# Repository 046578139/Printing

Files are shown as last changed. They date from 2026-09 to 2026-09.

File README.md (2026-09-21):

# NVG objective cap set

A four-piece 3D-printed objective cap system for NOCTIS mil-spec glass in
Nocturn Industries Raptor housings (AN/PVS-14-pattern objective interface),
retained with 1/8 in shock cord.

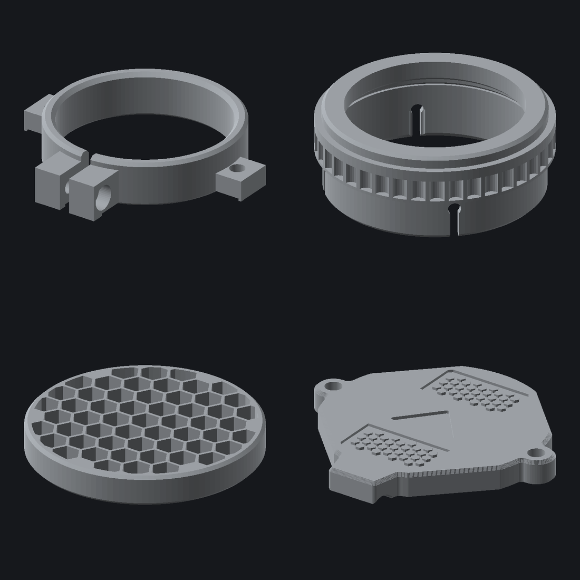
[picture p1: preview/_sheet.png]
parts


> ## Read this first
>
> **Front bezel: confirmed at 36.75 in PLA.** The fine ladder picked
> modelled bore 36.90, mid-ladder. That is 1.3 mm under the AN/PVS-14
> nominal this project started from — the nominal was wrong, which is
> exactly why the gauge exists. Valid in PLA only; re-gauge in the
> production filament.
>
> **Collar barrel: still unverified**, and suspect for the same reason.
> Do not print a collar until that number is read off a gauge.
>
> → **[docs/CALIBRATION.md](docs/CALIBRATION.md)** ·
> **[docs/MEASUREMENTS.md](docs/MEASUREMENTS.md)**

## The parts

| File | Part | What it does |
|---|---|---|
| `stl/sweep/cinchS_*.stl` | **Collar, cinch — print these** | Held by a **zip tie**, not by the plastic. 40 N of band tension against the 6 N a PLA spring ring manages, and it does not relax. Three bores covering 35.29–41.20 so the ungauged seat stops mattering; print all three, fit the one that lands. 9.00 mm tall so it clears a narrow locking collar. **Goes on BEFORE the housing.** |
| `stl/01g_collar_cinch.stl` | Collar, cinch (11 mm) | Same part, full height. Wider tie channel and thicker ears — use it only once you know the locking collar band is at least 11 mm wide. |
| `stl/01f_collar_lap.stl` | Collar, lapped | On ice, and worth revisiting in PAHT-CF. The recorder mount's actual mechanism: the band wraps 414° so its two ends lap past each other, each carrying a finger tab. **Squeeze** the tabs together and the lap shortens, which makes the circle bigger. 2.6 N — the lightest squeeze of any collar here. No hardware, no tools — [how it works](docs/ASSEMBLY.md#01f-is-the-one-to-print). **Goes on BEFORE the housing.** |
| `stl/01e_collar_pinch.stl` | Collar, pinch | Reads closed at 340°, tabs flanking a gap — you **spread** these, not squeeze them. Lowest install strain in the set and no sliding clearance for a slicer to get wrong, so it is the fallback if `01f`'s lap fuses. **Goes on BEFORE the housing.** |
| `stl/01_collar.stl` | Collar, screw clamp | Split band clamp, M3 pinch screw. The only one that can be fitted *after* the housing, and the only one with a preload you can re-tighten. |
| `stl/01b_collar_proto.stl` | Collar, wide gap | Prototype only. Opens far enough to clamp anywhere across the plausible range, for use before the collar seat has been gauged. Needs an M3 × 30 screw. |
| `stl/01c_collar_snap.stl` | Collar, push-on | Split C-ring, 230° wrap. Pushed straight on; the barrel cams it open. Superseded by `01e` — kept because it is the only spring ring that does not need an axial approach. |
| `stl/01d_collar_lever.stl` | Collar, lever | Circlip-style, 290° wrap with finger paddles. Superseded by `01e`, which does the same job at 340° for less strain and less force. |
| `stl/02b_killflash_housing_solid.stl` | Housing, no collet | Same housing with the collet slots deleted. Cleaner and stiffer, but a press roughly **1.7× tighter** — to fit *and* to remove. |
| `stl/02_killflash_housing.stl` | Kill flash housing | Presses onto the objective bezel, carries the kill flash, gives the cap a register to close on. |
| `stl/03_killflash_insert.stl` | Kill flash | Printed honeycomb. 71 % open area, 39° off-axis cutoff. |
| `stl/04_flip_cap.stl` | Flip cap | Bungee-retained cover. Cord bosses at 3 and 9, thumb tab at 6, hex grip, centre mark. |
| `stl/05_gauge_shroud.stl` | Fit gauge | Ring ladder for the housing bore. **Print this first.** |
| `stl/06_gauge_collar.stl` | Fit gauge | Ring ladder for the collar bore. **Print this first.** |
| `stl/sweep/lap_*.stl` | Fit sweep | Five `01f` collars stepping 0.30 mm, bore size moulded into each ear. Settles the collar seat *and* the grip on one plate — the last unverified dimension in the set. |

Every part is symmetric about the vertical plane — there is no left and
right. Print two of each for a binocular.

### Prototyping in PLA

Everything is calibrated for PLA right now (`CAL_MATERIAL == PRINT_MATERIAL`,
so the bore bias is exactly zero — the measured case). Print the whole set
in PLA, use `01b_collar_proto` in place of the collar, and you can shake
down cord routing, flip clearance, IPD spacing and glove ergonomics before
the collar barrel has been gauged and before committing any engineering
filament.

**Do not field a PLA set.** It creeps under the collet's sustained hoop load
and softens around 55–60 °C; an afternoon on a dashboard will destroy it.

## Quick start

```bash
python3 build.py        # writes one STL per part into stl/
python3 tests.py        # 332 geometry and interface checks
python3 render.py       # PNG previews into preview/
```

Fine-tune a fit without touching anything else:

```bash
python3 build.py gauge --nominal 38.4 --step 0.1 --count 7
```

Requires `manifold3d`, `trimesh`, `numpy`.

## How it goes together

```
   objective bezel │ kill flash │ housing flange │ register │ cap
   ────────────────┼────────────┼────────────────┼──────────┼──────
       8.0 mm      │   5.0 mm   │     1.6 mm     │  2.2 mm  │ 5.6 mm
                                                                     → +Z
   collar clamps the barrel behind all of this, cord runs forward at r=26
```

The kill flash loads from the **rear** of the housing and seats against an
integral flange, then the objective traps it. No snap ring, no glue, and it
still comes apart for cleaning. → **[docs/ASSEMBLY.md](docs/ASSEMBLY.md)**

## Design notes

**Both cord holes sit on one radius (26.00 mm).** That makes the line
between the two cap bosses the hinge axis, with both holes lying *on* it —
so flipping the cap does not change the cord length. The bungee only
stretches the 2.2 mm needed to clear the register, about 11 % strain.

**Nothing needs an anti-rotation key.** The cap's orientation comes from the
two cords, not from the register, so the housing is free to sit at any
rotation. The collar is screw-clamped because it *is* the rotational datum.

**Every part prints without support.** The housing goes front-face-down so
the kill flash seat becomes an upward-opening pocket; the cap goes
front-face-down so the decorated face gets the plate finish and the grip
texture is debossed rather than raised; the collar's nut trap is rotated
point-up so it bridges itself.

**The housing grip is a four-finger collet, and the fingers are thinner
than the wall.** A solid ring pressed onto an objective barrel has a narrow
acceptance window and puts real hoop stress into an expensive optic. But
slots alone are not enough — radial compliance scales as `t³/L³`, and at the
full 3.4 mm wall the fingers were a stubby plate (L/t = 1.88), not a spring.
There is not enough bezel to lengthen the slots, so the OD is relieved over
the collet instead: 1.90 mm fingers at L/t = 3.16 are **4.7× more
compliant**, at no cost in axial length. Each slot ends in a round keyhole
rather than a flat face, because the root is where it would crack.

**The slots' bore edges are broken.** Four slots leave eight sharp axial
edges in the bore that would otherwise scrape the full grip length of the
bezel on every install. On a coated optic that is the one piece of real
damage this design could do.

**The cap seats on the housing shoulder, not the register.** The pocket is
0.4 mm deeper than the register is tall, so the register locates and the
shoulder takes the load. A cap that lands on the register rocks.

## Layout

```
params.py           every dimension, single source of truth
build.py            emits one STL per part, validates before writing
tests.py            geometry probes + cross-part interface assertions
render.py           headless preview renderer (no GL)
lib/                solids, patterns, seven-segment text
parts/              one module per part
docs/               CALIBRATION, MEASUREMENTS, ASSEMBLY, PRINTING
stl/                output
```

`params.py` is the only file you should need to edit. Two hardware
diameters, plus `CAL_MATERIAL` / `PRINT_MATERIAL` — the bore bias is derived
from those, so changing filament is one line and cannot be got wrong by
forgetting. `BORE_TRIM` is there for a uniform fit correction on top.

## Material

| Part | Material |
|---|---|
| Collar, kill flash housing | **PAHT-CF** — expansion matched to the aluminium bezel, ductile across layers at the collet roots, immune to DEET and CLP |
| Kill flash, flip cap | **ASA Basic** — the 0.45 mm honeycomb wall needs a 0.4 mm nozzle, and CF grades need 0.6 mm hardened; the cap is the only impact-loaded part |
| Prototypes and coarse gauges | **PLA Basic** — not PETG, which is half the stiffness and yields where the production part cracks |
| Fine gauge | **the production filament itself** |

No single material wins all four parts. The reasoning, the tradeoffs being
accepted, and full slicer settings are in
**[docs/PRINTING.md](docs/PRINTING.md)**.

Carbon fibre against a coated objective barrel was **not** cleared — line
the collar bore with 0.13 mm PTFE tape and set `LINER_T = 0.13`.

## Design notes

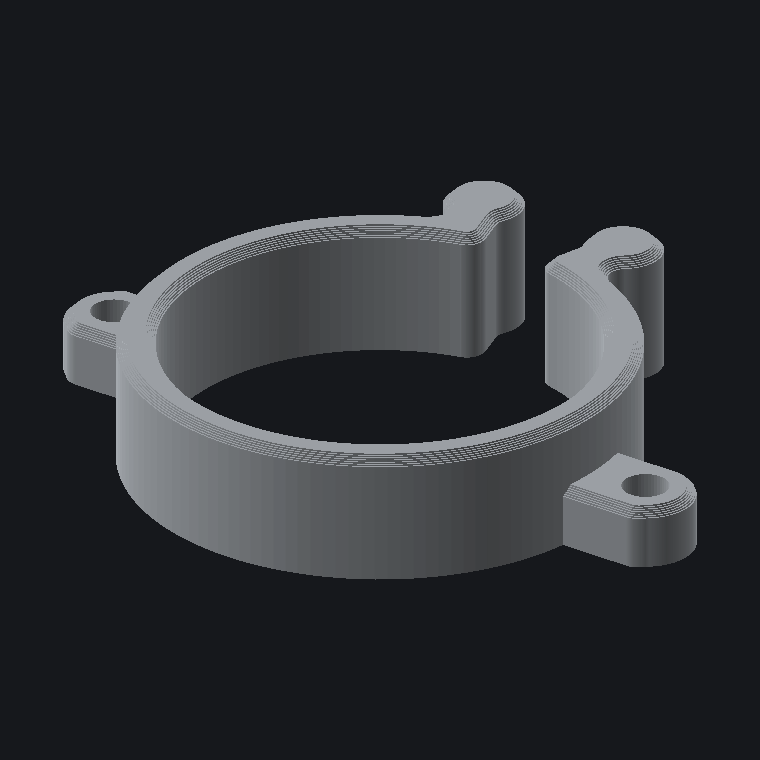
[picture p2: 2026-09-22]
preview/01e_collar_pinch.png

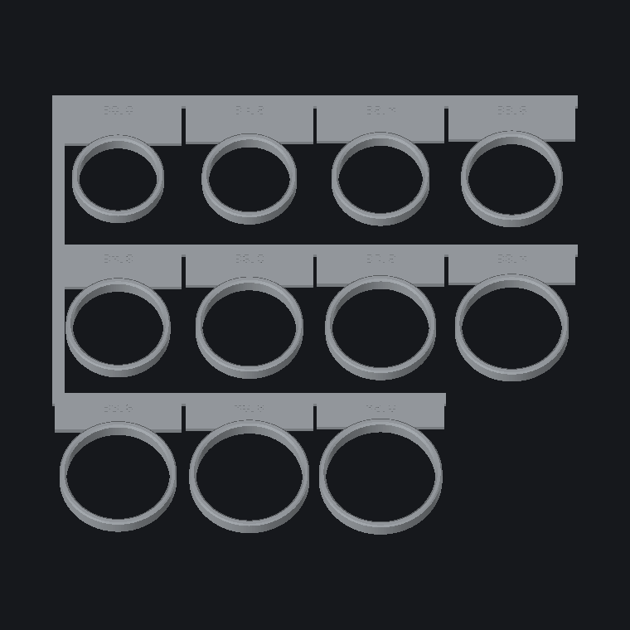
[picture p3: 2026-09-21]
preview/06_gauge_collar_wide.png

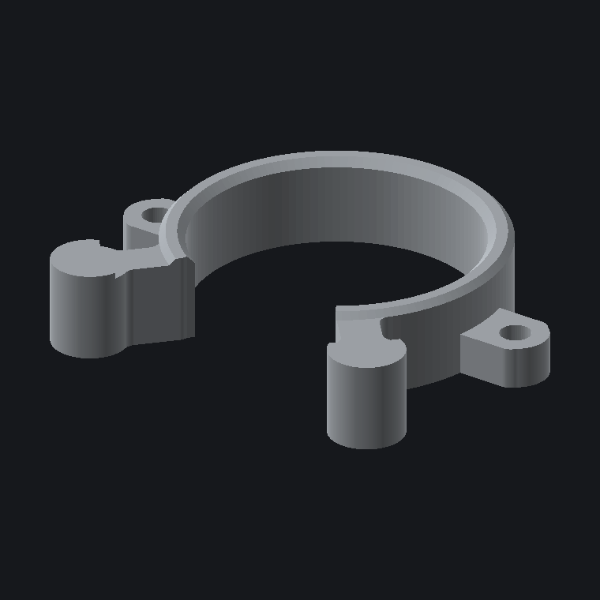
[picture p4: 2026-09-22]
preview/01d_collar_lever.png

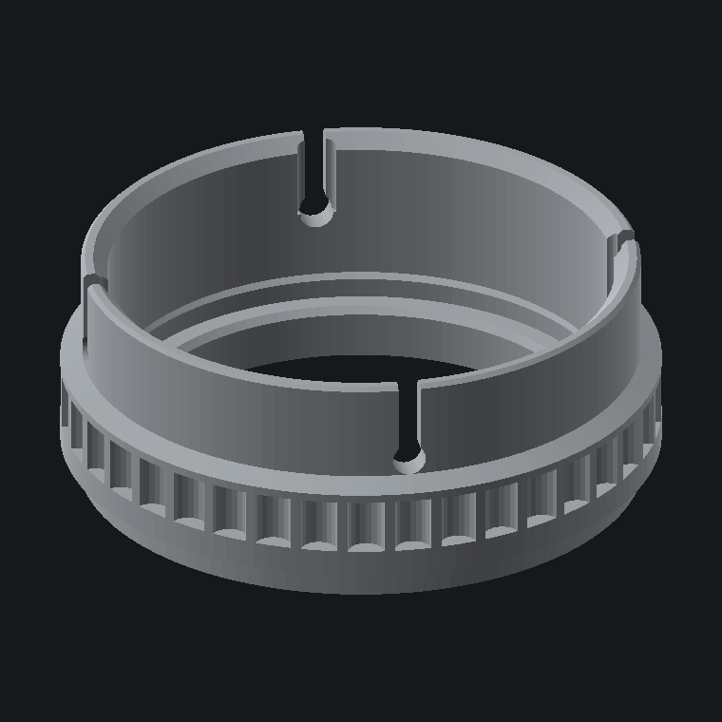
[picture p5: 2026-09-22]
preview/02_killflash_housing.png

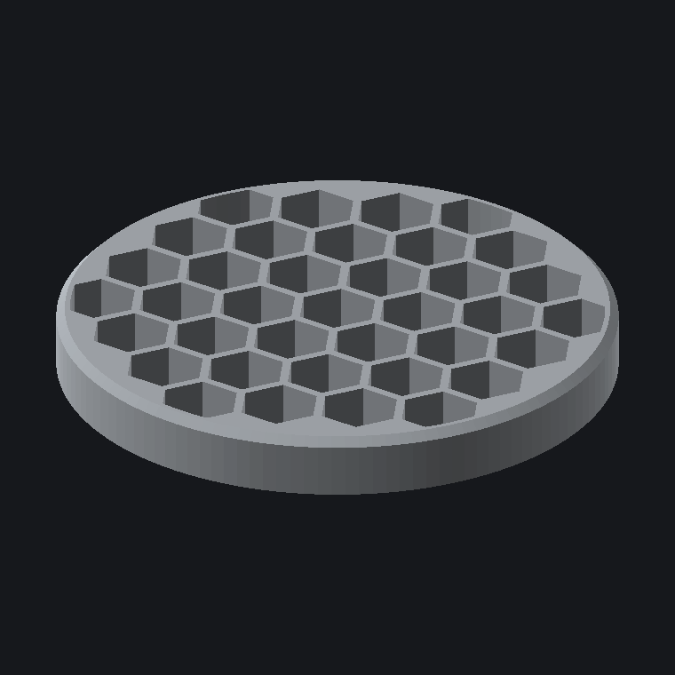
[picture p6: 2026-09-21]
preview/03_killflash_insert.png

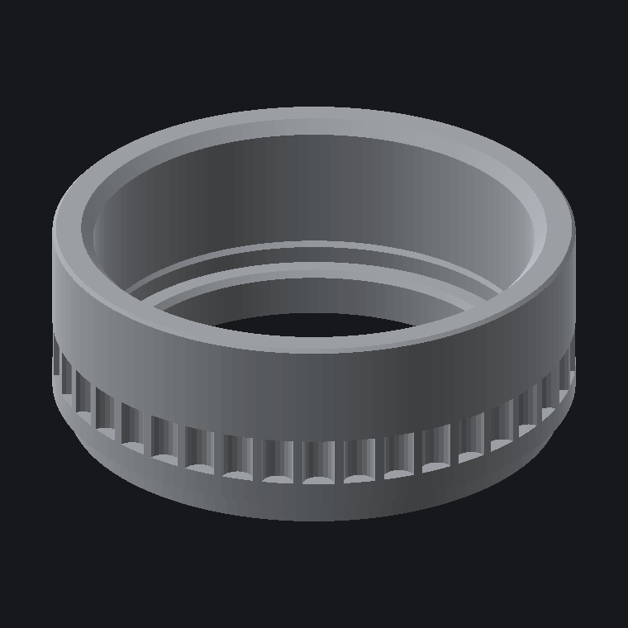
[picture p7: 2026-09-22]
preview/02b_killflash_housing_solid.png

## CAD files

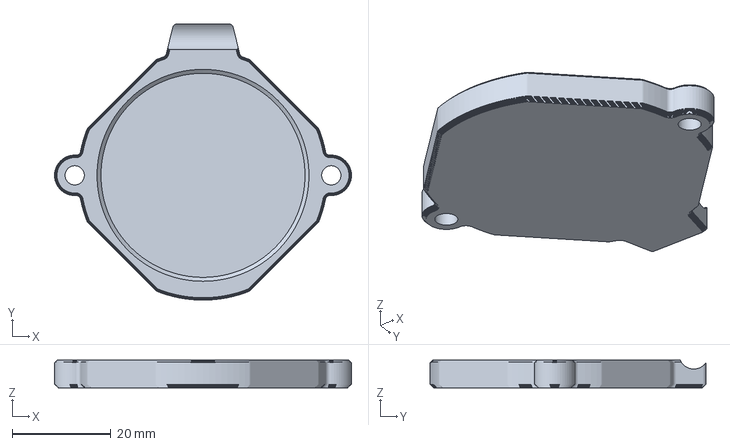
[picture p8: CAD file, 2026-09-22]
stl/20_cap_FUCK_2color.3mf
60.2 x 56.0 x 5.60 mm

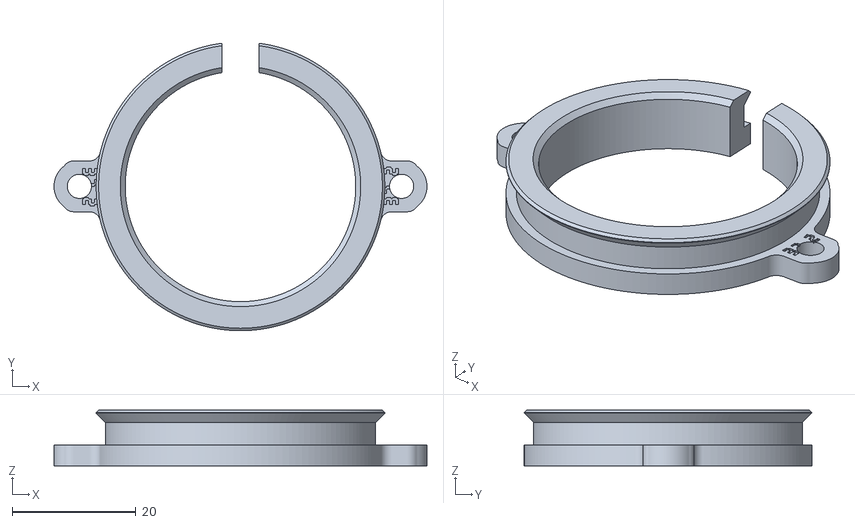
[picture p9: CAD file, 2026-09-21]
stl/sweep/cinchS_37.20.stl
60.2 x 46.4 x 9.00

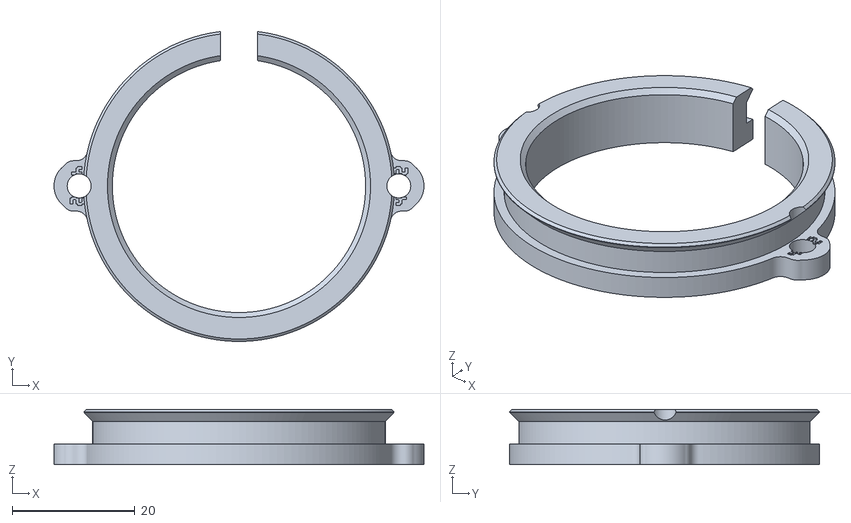
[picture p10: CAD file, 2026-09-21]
stl/sweep/cinchS_41.20.stl
60.2 x 50.4 x 9.00

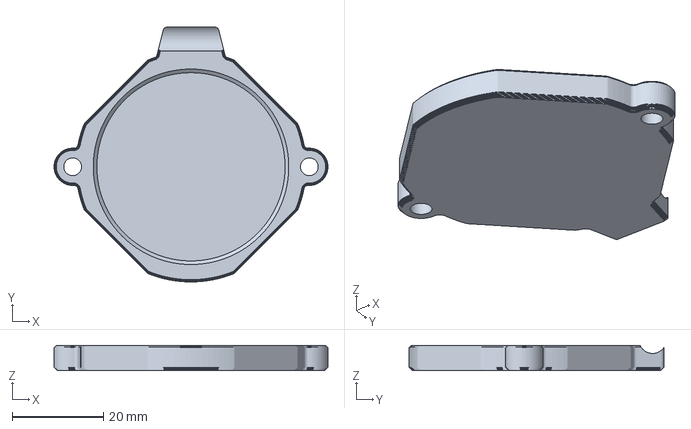
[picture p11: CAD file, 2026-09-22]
stl/23_cap_2color.3mf
60.2 x 56.0 x 5.60 mm

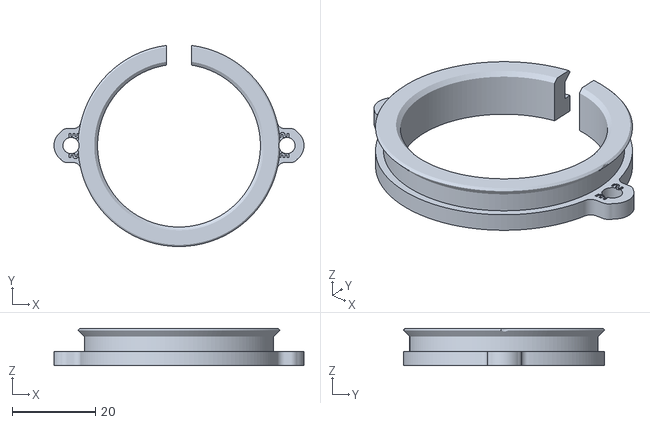
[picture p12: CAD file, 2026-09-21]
stl/sweep/cinchS_39.20.stl
60.2 x 48.4 x 9.00

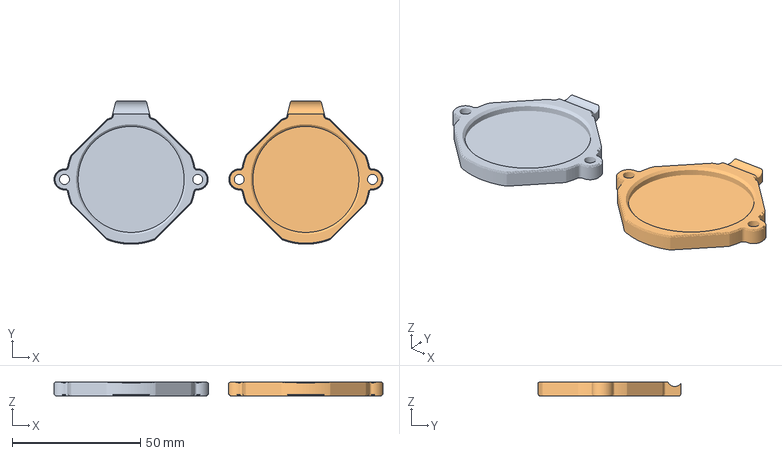
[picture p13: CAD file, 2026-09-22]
stl/22_caps_FUCK_YOU_2color.3mf
128.4 x 56.0 x 5.60 mm
FUCK cap
YOU cap

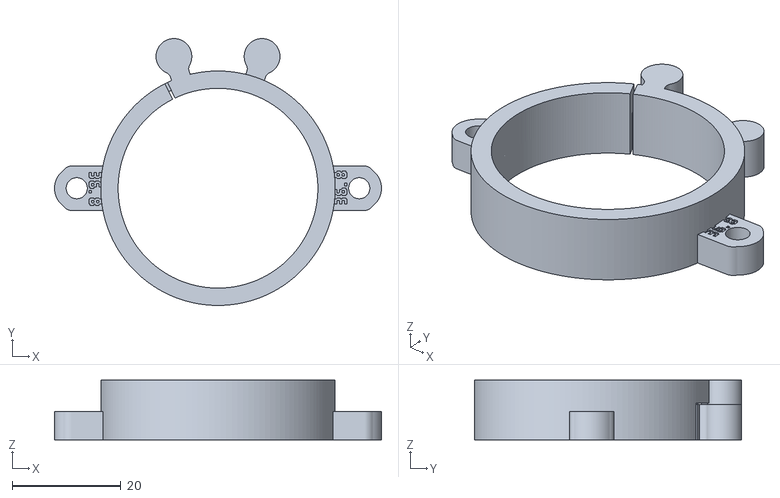
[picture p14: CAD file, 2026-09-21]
stl/sweep/lap_36.80.stl
60.2 x 49.2 x 11.0

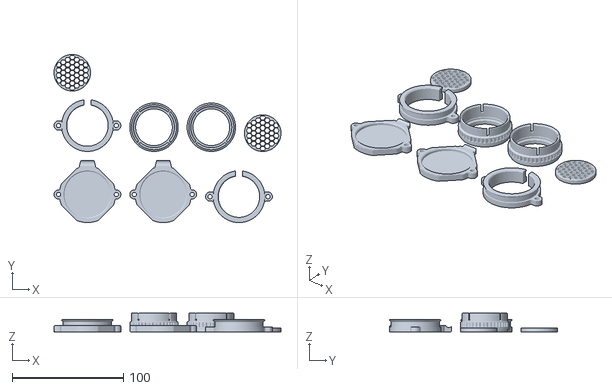
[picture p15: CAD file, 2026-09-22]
stl/11_plate_pair.stl
204.3 x 151.3 x 16.8

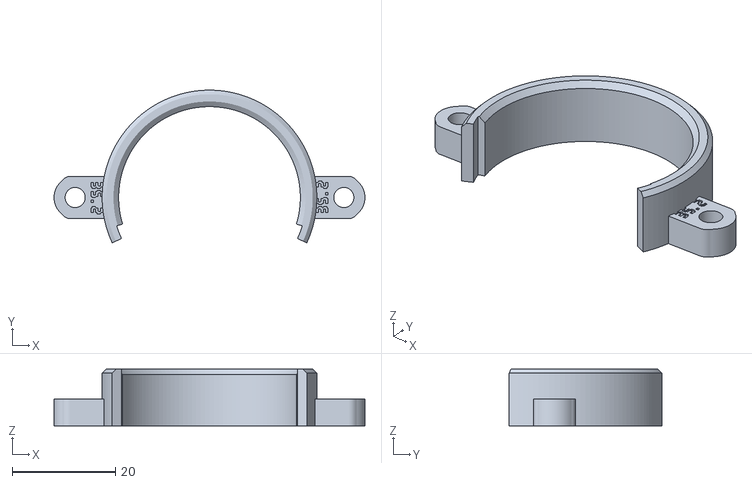
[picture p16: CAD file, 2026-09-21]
stl/sweep/snap_35.20.stl
60.2 x 29.6 x 11.0

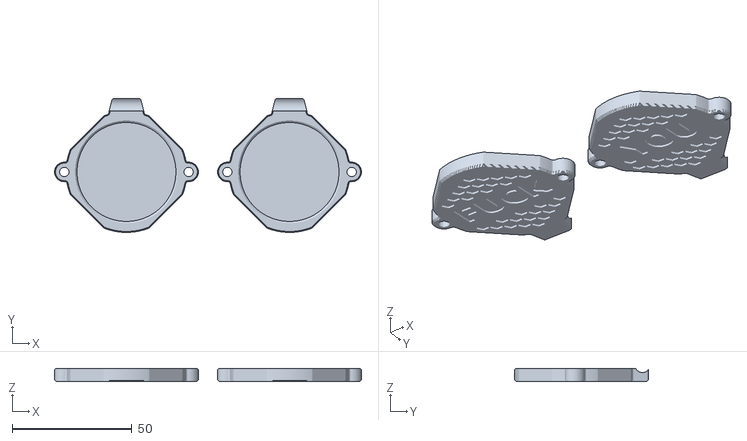
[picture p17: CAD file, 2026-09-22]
stl/12_plate_caps_FUCK_YOU.stl
128.4 x 56.0 x 5.60

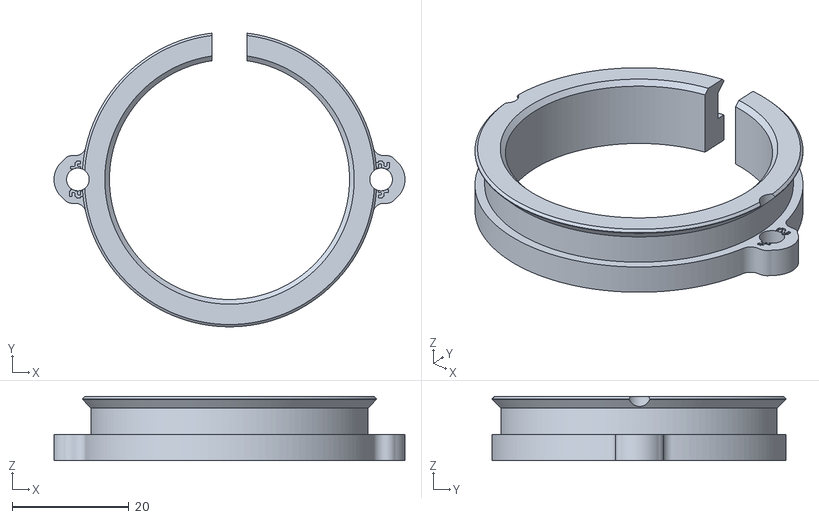
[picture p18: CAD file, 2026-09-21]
stl/sweep/cinch_41.20.stl
60.2 x 50.4 x 11.0

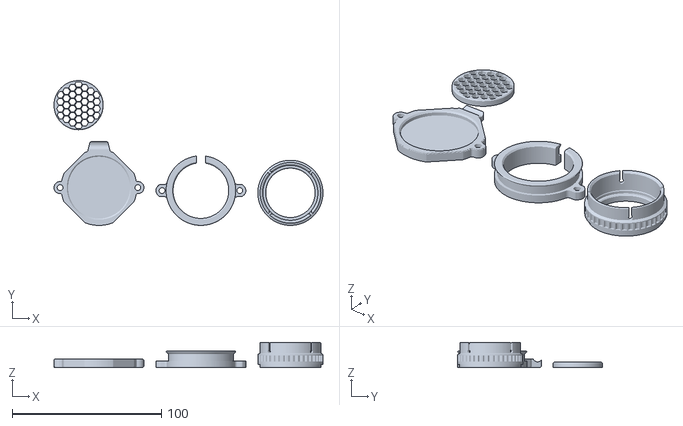
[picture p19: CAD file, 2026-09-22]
stl/10_plate_set.stl
180.0 x 96.9 x 16.8

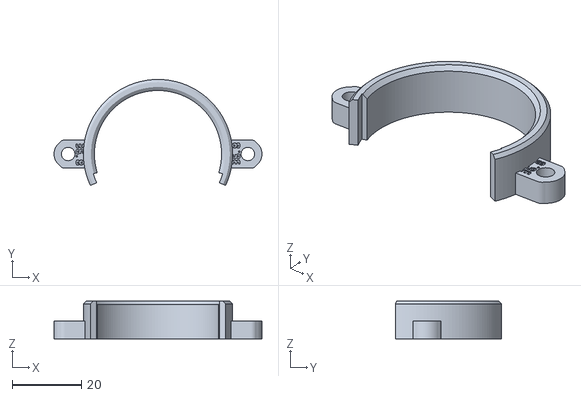
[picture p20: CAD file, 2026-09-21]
stl/sweep/snap_36.80.stl
60.2 x 30.7 x 11.0

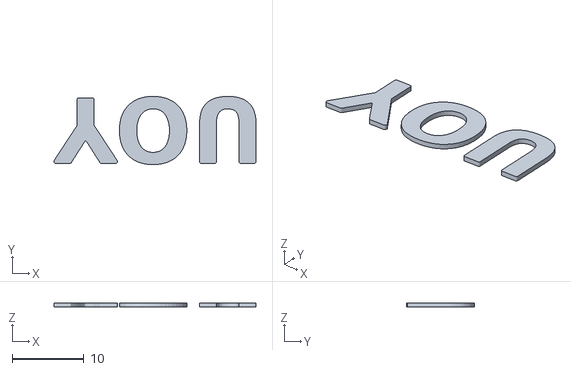
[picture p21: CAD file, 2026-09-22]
stl/04c_inlay_YOU.stl
28.2 x 9.50 x 0.6

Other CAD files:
stl/21_cap_YOU_2color.3mf
stl/sweep/lever_36.00.stl
stl/04_inlay_hex.stl
stl/sweep/lap_35.90.stl
stl/01_collar.stl
stl/01b_collar_proto.stl
stl/01c_collar_snap.stl
stl/01d_collar_lever.stl
stl/01e_collar_pinch.stl
stl/01f_collar_lap.stl
stl/01g_collar_cinch.stl
stl/02_killflash_housing.stl
stl/02b_killflash_housing_solid.stl
stl/03_killflash_insert.stl
stl/04_flip_cap.stl
stl/04_inlay_mark.stl
stl/04b_flip_cap_FUCK.stl
stl/04b_inlay_FUCK.stl
stl/04b_inlay_hex_FUCK.stl
stl/04c_flip_cap_YOU.stl
stl/04c_inlay_hex_YOU.stl
stl/05_gauge_shroud.stl
stl/05_gauge_shroud_nylon.stl
stl/05_gauge_shroud_petg.stl
stl/05_gauge_shroud_petg2.stl
stl/06_gauge_collar.stl
stl/06_gauge_collar_wide.stl
stl/07_gauge_killflash.stl
stl/sweep/cinch_37.20.stl
stl/sweep/cinch_39.20.stl
stl/sweep/kf_cell_03.4.stl
stl/sweep/kf_cell_04.2.stl
stl/sweep/kf_cell_05.0.stl
stl/sweep/kf_od_32.80.stl
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

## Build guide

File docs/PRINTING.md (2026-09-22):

# Printing

Bambu Lab H2C. **The nozzle is a design input, not a slicer setting.**

`params.py` currently declares `NOZZLE = 0.60`, `LAYER = 0.30` — the draft
setup — and every thin feature in the project is derived from it: cell
walls, texture grooves, rim widths, deboss depths. Change the nozzle at the
machine and you must change it in `params.py` and rebuild, or features that
were sized for the old one quietly fall below what the new one can extrude.

`tests.py` runs a minimum-feature audit against `NOZZLE` on every build. It
is the most useful test in the file: the first kill flash shipped with
0.45 mm cell walls on a 0.60 nozzle — 75 % of nozzle diameter, below what
can be extruded at all — and the slicer discarded every cell. The part came
off the plate as a bare rim with stubs.

### 0.6 / 0.3 draft vs 0.4 / 0.2

Keep the 0.6 for fit work. Fits are diameter-driven, not resolution-driven,
and as long as the gauge and the part are printed the same way the error
cancels — that is the whole basis of the calibration. Draft speed is worth
more than surface finish while the dimensions are still moving.

Drop to 0.4 / 0.2 for:

- **The cap**, if you want the grip texture to read as hexagons rather than
  bumps and the centre mark to come out crisp. At 0.6 those features are
  near the floor of what can be resolved, which is exactly how they printed.
- **Anything final**, and anything in carbon fill — which needs a hardened
  nozzle regardless.

If you do switch:

```
python3 build.py --nozzle 0.4 --layer 0.2        # whole set
python3 build.py cap --nozzle 0.4 --layer 0.2 --tag fine   # just one part
```

Cell wall, texture groove, rim and deboss depths all follow automatically.

### When to switch — batch it, don't pay twice

**A nozzle change invalidates the fit calibration.** A different nozzle
delivers a different bore, so the gauge reading you earned at 0.6/0.3 does
not carry across and every press fit has to be re-gauged.

Right now the housing fits, and that is a calibrated state worth keeping.
You will have to re-gauge anyway when you move to PAHT-CF or ASA, because
every production filament needs its own calibration and carbon fill needs a
hardened nozzle regardless. **Do both at once** and you pay the calibration
cost once instead of twice.

The exception is the **cap**, which can switch on its own. Its only fit is
0.35 mm of clearance over the register — loose enough that a nozzle change
cannot break it. So if you want the grip texture to read as hexagons rather
than bumps, print `04_flip_cap_fine` at 0.4/0.2 and leave everything else
where it is.

## Orientation

Every part is modelled so that it prints **without support** in one specific
orientation. Get these wrong and you will be picking support out of a kill
flash seat.

| Part | Orientation | Why |
|---|---|---|
| `01f_collar_lap` | **Rear face down** — already oriented, flat on the plate | Same reason as `01e`, plus: the lap's two sliding clearances (0.40 mm radial, 0.30 mm vertical) are only clearances in *this* orientation. Turn OFF thin-wall detection and gap filling — a slicer that helpfully bridges those two gaps welds the arms together and the ring will not expand at all |
| `01e_collar_pinch` | **Rear face down** — already oriented, flat on the plate | Cord ears at the bottom so they are not a mid-air overhang. Printed this way the band flexes *within* its layers when you spread the tabs, so installing it loads X-Y strength and never tests layer adhesion — which is the whole reason a printed spring ring works at all |
| `01_collar` | **Rear face down** — cord ears and clamp lugs on the plate | Ears sit at the bottom so they are not a mid-air overhang; the hex nut pocket is rotated point-up so it bridges itself |
| `02_killflash_housing` | **Front face down** — register on the plate | Makes the kill flash seat an upward-opening pocket. The only overhang is a 1.3 mm shoulder ledge, which bridges clean |
| `03_killflash_insert` | **Flat**, either way up | Symmetric |
| `04_flip_cap`, `04b`, `04c` and every `_inlay` | **Front face down** — decorated face on the plate | Register pocket, thumb scoop and cord holes all open upward; the grip texture is debossed rather than raised specifically so the face can lie flat |
| `05/06_gauge` | **Flat as generated** | — |

No supports on anything. If your slicer wants to add some, you have it the
wrong way up.

## The thing that will actually bite you: first-layer squish

Elephant's foot makes the first layer wider than the rest. On the parts here
that is not cosmetic — it lands directly on the bore that has to fit your
objective:

- The **collar** prints bore-vertical, so the first layer bulges *into* the
  bore at the bottom.
- The **gauge rings** do exactly the same thing.

That is fine, and it is why the gauges work: as long as the gauges and the
real parts are printed with **the same elephant's-foot compensation, the
same plate, and the same first-layer settings**, the error cancels. A gauge
printed differently from the part is measuring the wrong thing.

Set elephant's-foot compensation (Bambu Studio: *Quality → Elephant foot
compensation*) once, to whatever you normally use, and then do not touch it.

## Settings

### Everything except the kill flash

| Setting | Value | Note |
|---|---|---|
| Layer height | 0.20 mm | 0.16 for a nicer cap face |
| Wall loops | **4** | 3 minimum; these are load-bearing walls, not shells |
| Top / bottom layers | 5 / 5 | |
| Infill | **25 % gyroid** | Gyroid, not grid — it is isotropic, which matters for the cord bosses |
| Seam position | **Aligned**, and move it off the collet slots and cord bosses | A seam up a boss is where it will tear |
| Brim | Off, except the cap | |

### Kill flash insert — the one part with special settings

The cell walls are a **single 0.45 mm extrusion**. Slicers drop thin walls by
default and you will get a disc full of holes.

| Setting | Value |
|---|---|
| Detect thin walls | **ON** |
| Wall loops | 1 |
| Top / bottom layers | 0 |
| Infill | 0 % |
| Slow down for overhangs | Off |

Slice it and **look at the preview** before you print. Every cell wall should
show as a continuous extrusion. If cells are missing, raise `KF_WALL` in
`params.py` to 0.50 and re-slice.

### Flip cap

Print a **brim**. It is a 52 mm flat plate with a thin edge chamfer and it
will lift at a corner otherwise. The debossed grip texture and centre mark
are on the plate side, so plate finish is what you see — a smooth PEI sheet
gives a satin face, a textured sheet gives a matte one. For night vision,
**textured**: no glint.

### Two-tone face — use the 3MF

**An STL cannot carry colour.** It is a bag of triangles with no notion of a
part or a filament, so no amount of combining produces a two-tone cap. That
is what 3MF is for: objects, the parts inside them, and which extruder each
part prints with.

| File | Contents |
|---|---|
| `20_cap_FUCK_2color.3mf` | FUCK cap, body + lettering + hex |
| `21_cap_YOU_2color.3mf` | YOU cap, same |
| `22_caps_FUCK_YOU_2color.3mf` | Both caps on one plate |
| `23_cap_2color.3mf` | The standard P cap |

Each is **two filaments**: body on slot 1, lettering and hex field both on
slot 2. Three parts, two colours. Open it, check the filament slots on the
right match what is loaded, slice. Nothing to position or assign.

`python3 tools/make_3mf.py` regenerates them. Swap `GREY`/`TEAL` at the top
of that file to move a part to a different slot.

#### If the 3MF does not come in right

Load `04b_flip_cap_FUCK.stl`, then right-click it → **Add Part → Load** and
pick `04b_inlay_FUCK.stl`, then again for `04b_inlay_hex_FUCK.stl`. Click
each inlay in the object tree and set its filament. Same result, three
clicks.

### The inlay files

The decorated face can be printed in two or three filaments. Every recess on
it has a matching **inlay** file that fills it exactly flush:

| Cap | Lettering inlay | Hex field inlay |
|---|---|---|
| `04_flip_cap` | `04_inlay_mark` | `04_inlay_hex` |
| `04b_flip_cap_FUCK` | `04b_inlay_FUCK` | `04b_inlay_hex_FUCK` |
| `04c_flip_cap_YOU` | `04c_inlay_YOU` | `04c_inlay_hex_YOU` |

In the slicer: load the cap, then **right-click → Add Part → Load** each
inlay you want, and assign it a filament. They come in already aligned to the
cap, so **do not move or rotate them** — that is the whole reason they are
separate files rather than something to position by eye.

Mix freely: lettering only, field only, or both in different colours. Take
the inlays from the same cap as the body, though. The hex field is cut around
the lettering, so `04b_inlay_hex_FUCK` on a YOU cap puts plugs where the
letters are.

**This is the easier print, not the harder one.** Debossed and printed face
down, every letter floor and every dimple floor is a ceiling bridged over
air. Filled with a second filament there is no void left to bridge — the
whole face builds off the plate as one solid first layer.

What it costs is purge. The recesses are 0.60 mm deep, so the swaps are
confined to the first five layers at 0.12 — but within those five layers the
lettering is one compact region while the hex field is 30–40 plugs scattered
over the whole face. Both want a tool change per layer regardless; the field
just makes those layers longer. Five layers of swaps is a few grams of purge,
not a few tens.

## One-file plates

Three files carry a whole plate, parts already laid out and oriented:

| File | What's on it | Footprint |
|---|---|---|
| `10_plate_set` | One pod: cinch collar, housing, kill flash, cap | 180 x 97 mm |
| `11_plate_pair` | A full binocular set, two of each | 204 x 151 mm |
| `12_plate_caps_FUCK_YOU` | Both custom caps | 128 x 56 mm |

Drop one on the bed and slice. Everything is spaced 8 mm apart, which is a
brim's width, and nothing needs rotating.

Two things a plate **cannot** do:

**Colour.** An STL carries geometry and nothing else. The cap inlays are
separate files precisely so the slicer can hand each one its own filament;
merged onto a plate they would just be more plastic. Two-tone stays on the
individual files above.

**Per-part settings, unless you load it as multiple parts.** The kill flash
wants 1 wall loop, 0 top/bottom and thin-wall detection ON, and the rest of
the set very much does not. When the slicer asks *"multi-part object
detected — load as a single object with multiple parts?"* answer **yes**:
you can then right-click the insert in the object tree and set them on that
part alone. Answer no and the whole plate gets one set of settings, and the
insert comes out a disc full of holes.

If you would rather not deal with that, print `10_plate_set` without the
insert selected and run `03_killflash_insert` on its own — it is 25 minutes.

Each plate has a matching `.svg` next to it in `stl/`, a top view of the
layout on the bed. `python3 tools/plate_preview.py` regenerates them.

## Print order

1. **`05_gauge_shroud` and `06_gauge_collar` first.** ~20 min each. Do not
   skip this. → [MEASUREMENTS.md](MEASUREMENTS.md)
2. Set the two numbers, rebuild, then print **one** housing and check it on
   the objective before committing to a full set.
3. Then the rest, two of each.

Rough times at 0.2 mm on an H2C: collar ~35 min, housing ~40 min, kill flash
~25 min, cap ~45 min. A full binocular set is about 5 hours of machine time
and roughly 80 g of filament.

## Moving between materials

Prototype and production materials do **not** shrink the same amount, so a
bore that fit in PETG will not fit in a carbon-filled resin. That is what
`BORE_BIAS` in `params.py` is for — one number that trims every
hardware-facing bore at once:

```python
BORE_BIAS = +0.15   # production part comes out tighter than the prototype
```

The honest way to find that number is to reprint the **gauge** in the
production material and compare which ring wins. It costs one 20-minute
print and removes all the guesswork.

## Material selection

Short version: **you already own the right material for the two parts that
grip the optic. Buy one spool of ASA Basic (~$30) for the other two.**

| Part | Material | Have it? |
|---|---|---|
| 01 collar | **PAHT-CF** | yes |
| 02 kill flash housing | **PAHT-CF** | yes |
| 03 kill flash insert | **ASA Basic** | order |
| 04 flip cap | **ASA Basic** | order |
| gauges (coarse) | **PLA Basic** | — |
| gauges (fine) | **the production filament** | — |

No single material wins all four parts. Every attempt to claim one — ASA for
the set, PET-CF for the set, PAHT-CF for the set — failed an adversarial
review. Split it.

### Why PAHT-CF for the collar and housing

**Thermal expansion match to the aluminium bezel.** This is the term that
decides it, and it is the one nobody thinks about. Aluminium is ~23 ppm/K.
Fibre-filled grades run 25–35 ppm/K in the hoop direction; every *unfilled*
polymer — ASA, ABS, PC, PETG, PLA — runs 60–95. Over a −20 °C to +60 °C
service span an unfilled shroud gains or loses **0.06–0.10 mm** of
interference. The whole design fit is 0.15 mm. A fibre-filled one moves
~0.01 mm. For plastic clamped on metal, fibre fill is not a strength choice,
it is a dimensional requirement — and it disqualifies unfilled materials for
these two parts outright.

**Ductility across layers at the collet roots.** The housing prints
front-face-down, so the collet fingers bend *across* layer lines and Z
properties govern, not the headline X-Y numbers. PAHT-CF: ~5.2 % Z
elongation. PET-CF: ~2.4 %. On a notched feature that cycles every time you
pull the shroud to clean the kill flash, that is the difference between a
part that flexes and one that snaps.

**Chemistry and heat.** Semi-crystalline polyamide is the only class here
with real resistance to DEET, CLP and sunscreen esters — and the housing is
the one part under *permanent* strain, which is the textbook precondition
for environmental stress cracking. HDT ~170 °C makes a closed summer vehicle
a non-event. PET-CF's Tg is ~75 °C, so as-printed it sits essentially *at*
its glass transition under sustained collet load, and you cannot anneal it
without destroying the bore.

**The tradeoff being accepted:** PAHT-CF absorbs moisture (~0.88 %), which
grows the bore roughly 0.03–0.06 mm from dry to equilibrium over 2–3 weeks.
That is real. It is also a *calibration* cost rather than a defect, and it
cancels completely if you gauge in conditioned PAHT-CF — see
[MEASUREMENTS.md](MEASUREMENTS.md). Trading a reversible, measurable offset
for PET-CF's irreversible creep near Tg is the right call for field gear.

**Do not use the PPA-CF for the housing when it arrives.** It is a fine
material, but it is another semi-crystalline polyamide with the same
moisture discipline and no advantage here, and every production filament
needs its own gauge calibration. Save yourself a second calibration.

### Why ASA for the kill flash and cap

**Kill flash — this one is not close.** `KF_WALL` is a 0.45 mm *single
extrusion*, which needs a 0.4 mm nozzle. Bambu's guidance for every CF grade
is a 0.6 mm hardened nozzle to avoid fibre clogs. At 0.45 mm the chopped
fibre bundles are the same order as the wall itself — the filler stops being
reinforcement and becomes a defect population spread over ~81 cells and
~14 m of single-wall path per part. Unfilled is the materially correct
answer. UV matters most here too: photo-oxidation is skin-depth limited and
a 0.45 mm wall cannot afford to lose 100 µm. ASA's acrylate rubber has no
butadiene to photo-oxidise. Treat the insert as a consumable and reprint it
every year or two.

**Cap — the only genuinely impact-loaded part.** ASA publishes ~19.6 kJ/m²
notched Charpy: roughly 2.3× PET-CF's X-Y figure and 4× its Z figure. Bambu
publishes *no* notched figure for PAHT-CF at all, and a daily-pried thumb
tab is not something to spec on a missing number. ASA is also unfilled, so
it cannot abrade the register or shed fibre near the glass, and its lower
modulus closes quieter — which matters at night. `CAP_SKIRT_BORE` has
0.35 mm of clearance, so ASA's higher expansion is irrelevant here.

**If you would rather not order anything:** PETG is an acceptable fallback
for both of these. It gives up UV life on the insert and impact on the cap,
but it will work, it needs no hardened nozzle, and you likely have it.

### Carbon fibre against your objective — read this

This was **not** cleared. The comfortable argument ("CF is softer than
anodising") was refuted three ways: it contradicts Bambu's own mandatory
hardened-nozzle requirement, it ignores that in mud and sand the *polymer*
is the grit-embedding member, and it says nothing about the carbon/aluminium
galvanic couple in salt and rain.

Two mitigations, both cheap:

1. **Line the collar bore** with 0.13 mm self-adhesive PTFE or UHMW tape.
   Non-conductive (kills the galvanic loop), slippery, inert, sacrificial.
   Set `LINER_T = 0.13` in `params.py` and the bore opens to suit. The collar
   is the higher-risk part — it clamps 11 mm of barrel under sustained screw
   load.
2. **The housing's bore edges are already broken in CAD.** The four collet
   slots used to leave eight square axial edges that would scrape the full
   grip length of the bezel on every install; `SLOT_EDGE_BREAK` now relieves
   them. Nothing for you to do, but do not set it to zero.

Never bead-blast a bore. Leave it as printed.

**No TPU liner.** Abrasive embeds in the softer member and laps the harder
one, so a TPU sleeve in mud becomes a grit-charged lap against your bezel.
It also has 150–200 ppm/K expansion and heavy compression set. PTFE is soft
*and* slippery; TPU is only soft.

### Why PLA and not PETG for prototypes

PETG is the intuitive choice and it is the wrong one, for two specific
reasons:

- **Stiffness.** Your acceptance test is a hand-felt seating force, and
  collet force scales with modulus. PETG (~2050 MPa) under-reports seating
  force against PAHT-CF (~4120 MPa) by about half. PLA Basic (~2750 MPa) is
  off by a third. PLA-CF (~3950 MPa) is within 4 %.
- **Failure mode.** PETG is ductile — at over-interference it *yields* and
  then reports "fits fine". PAHT-CF and PET-CF crack. A proxy that cannot
  reproduce the production failure mode cannot validate margin against it.
  PLA is brittle and fails the way the real part will.

PLA is also the lowest-shrink, no-drying, no-hardened-nozzle material on the
shelf, which is exactly what a measurement artifact should be.

If you want one high-fidelity check before committing nylon, print a single
housing in **PLA-CF**: within 4 % of PAHT-CF's modulus, fails brittle, and
genuinely matte so the same print also reads out glint and whether the
0.45 mm honeycomb resolves.

### What would change this

Stated plainly, because some of it is inference rather than published data:

- **PET-CF takes the housing back** if you condition a PAHT-CF ring and a
  PET-CF ring side by side for a month and the PAHT-CF bore has moved more
  than ~0.06 mm. The case rests on the swell being fibre-restrained in the
  hoop direction; Bambu publishes no dimensional-change coefficient, so that
  is inferred.
- **PET-CF also wins** if you decide you will essentially never remove the
  housing. The argument leans on the fingers cycling.
- **PAHT-CF takes the cap** if Bambu ever publishes a notched Charpy for it
  above ~15 kJ/m². Cheap test that settles it yourself: freeze one of each
  overnight at −20 °C and break the thumb tabs by hand. Nobody publishes
  low-temperature impact figures for these, so that is the only data that
  will ever exist.

## Settings by material

### PAHT-CF — collar and housing

| Setting | Value |
|---|---|
| Nozzle | **0.4 mm hardened steel, mandatory.** Not a high-flow hotend — a CF clog there is effectively unclearable |
| Nozzle / bed | 280 °C / 100 °C, textured PEI |
| Chamber | **60–65 °C, actively heated.** This is what drives interlayer strength, which is exactly what the collet roots need |
| Drying | **80 °C for 8–12 h before, and keep it dry during.** Wet nylon means poor layer adhesion at the slot roots — the one place you cannot afford it |
| Wall loops | **5** — the grip section is load-bearing and Z-loaded |
| Part cooling | 20–30 % max |
| Speed | ≤100 mm/s outer walls; slow through the collet |
| Seam | Aligned, **forced off the collet slots and the pinch lug** — a seam at a slot root is where it cracks |
| Brim | **Yes on the housing.** Its first layer is a ~550 mm² annulus carrying a tall part, and it is the surface that sets `REG_OD` |

### ASA Basic — kill flash and cap

| Setting | Value |
|---|---|
| Nozzle | 0.4 mm standard — **no hardened nozzle needed**, the only fieldable material here that can say that |
| Nozzle / bed | 255 °C / 100 °C, textured PEI |
| Chamber | 50–60 °C |
| Drying | 80 °C for 6–8 h. Not needed during the print |
| Part cooling | **0–15 % on the cap** — styrenics delaminate and warp with fan |
| Brim | **Yes on the cap** |

**The honeycomb has one genuine conflict:** ASA wants almost no fan, but the
insert's layers are short (~560 mm of single-wall path) and need to set
before the next one lands. Do not solve it with the fan. **Put 4–6 inserts
on the plate at once** — that multiplies layer time by 4–6× and lets you
keep the fan at 20–30 % in a hot chamber. Also drop the speed to 30–40 mm/s;
this part has no reason to be fast.

### PLA Basic — prototypes and coarse gauges

| Setting | Value |
|---|---|
| Nozzle / bed | 220 °C / 55 °C |
| Chamber | **Off, door open** — a hot chamber heat-creeps PLA in the extruder |
| Drying | none |
| Layer / walls / infill | **match your production settings exactly**, or the gauge means nothing |
| Part cooling | 100 % |

Honeycomb prints beautifully in PLA Basic — it is the best thin-wall
material of the lot, which is why it is the right proxy for checking whether
the cells resolve.

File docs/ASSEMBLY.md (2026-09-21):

# Assembly

Per eye: 1 collar, 1 kill flash housing, 1 kill flash insert, 1 flip cap,
and about 240 mm of 1/8 in (3.175 mm) shock cord. Double it for a binocular.

The recommended collar is **`01g_collar_cinch`** (short version), which
needs one 3.6 mm zip tie and no tools. If you print a screw collar instead, add 1 M3 socket head cap
screw and 1 M3 hex nut per eye: **16 mm** for `01_collar`, **30 mm** for
`01b_collar_proto` — the prototype's pinch gap is 13 mm wide, so the screw
has to span a lot more air before it closes.

Every part is symmetric about the vertical plane, so there is **no left and
right** — print two of each and they fit either pod.

## Order of operations

> **With a spring collar (`01c` / `01d` / `01e` / `01f`) the collar goes
> on FIRST.**
> None of them will pass over the Ø43.7 housing, so the order below is
> 0 → 1 → 2 → 4. Only the screw collars can be fitted after the housing,
> because they open all the way. Get this wrong and you are pulling a very
> tight press fit back off a coated objective.

**0. Collar onto the LOCKING COLLAR — the fixed band immediately behind
the focus ring, NOT the focus ring itself.** The bezel turns to focus and
has play in it; more importantly the cap's register is circular, so the
cap's orientation is held entirely by these two cords. On the fixed band,
focusing just spins the housing under the cap and the thumb tab stays put.

Slide the collar on from the front, over the bezel, then run a 3.6 mm zip
tie round the channel and pull it tight. It must go on BEFORE the housing —
it will not pass over the Ø43.65 flange afterwards.

*(Spring collars `01c`–`01f` instead —
skip to step 1 for a screw collar and come back at step 3.)*

Cord ears at 3 and 9 o'clock, ears facing **rearward**, lap or gap at 12.

- On **`01f`**, pinch the two tabs **together** — they sit at different
  heights and lap past each other, so they will not butt. About 4 N. The
  lap shortens from 30° to 18° and the bore grows 1.30 mm.
- On **`01e`**, get a fingertip between the two tabs and **spread** them
  apart instead. About 5 N; the gap opens from 6.8 to 10.9 mm.

Slide the ring down the bezel to its seat and release.

Before you let go, confirm the band is not sitting on anything that turns
when you focus. On a PVS-14-pattern objective the focus ring turns, and a
collar clamped to it will bind the focus.

It should not rotate under a firm hand twist. If it does, the bore is too
big — print the `lap-bore` (or `pinch-bore`) sweep and step down.

**1. Housing onto the objective.**
Push the housing straight on, front face forward. Go square — the rear bore
lead-in will help, but a cocked start will gall the bezel. It bottoms
positively against the internal flange; that is the depth stop and it is
hardware-confirmed. Do **not** force a fit that clearly does not want to go;
go back to the gauge.

**2. Kill flash into the FRONT recess.**
The insert presses into the Ø33.00 counterbore on the **front** of the
housing, chamfered edge leading, and seats on the flange 0.20 mm under
flush. Light thumb pressure.

It does not go in from the rear — the objective fills the whole bore and
bottoms on the back of that same flange, so there is no rear pocket. If the
press is wrong, print `07_gauge_killflash`: five plugs stepping 0.15 mm, and
you want the largest one that seats with thumb pressure and does not fall
out when inverted. Put that number in `KF_OD`.

A note on why this needed a gauge at all: an FDM hole comes out undersize
and an FDM boss comes out oversize, and here those two errors stack against
each other on the same 0.30 mm clearance. That is a fit worth measuring
rather than calculating.

**3. Screw collar onto the barrel.** *(Skip if you fitted a spring collar
at step 0.)*
Slide it on behind the housing with the two cord ears at 3 and 9 o'clock,
ears facing **rearward**, and the pinch lugs at 6 o'clock. Confirm one more
time that the band is not sitting on anything that turns when you focus.

Fit the M3 screw from the right-hand lug (counterbored for the head) into
the hex nut trap on the left. The nut pocket is oriented point-up so it
prints without support; press the nut in with a flat blade before starting
the screw.

Snug it until the collar will not rotate under a firm hand twist. It does
not need to be tight — you are clamping an optical assembly, not a
suspension arm. If the gap closes completely before it grips, the bore is
too big; if it grips with the gap barely closed, that is correct.

On the **prototype** collar the gap will close a long way before it grips,
and that is expected — that is the whole point of it. Note roughly how far,
though: a gap that ends up near 0 means the real barrel is close to
38 mm, and one that stays wide means it is close to 42. That is a free
coarse reading while you wait to print the proper gauge.

**4. Cord.**
Cut four pieces about 120 mm each. Per side, per eye:

```
  knot ── collar ear ──────── forward ──────── cap boss ── knot
 (behind)                                              (in front)
```

- Thread from the rear: through the collar ear, forward, through the cap
  boss from the back.
- Tie a figure-eight in the tail behind the collar ear first.
- Hold the cap closed on the housing, pull the front tail until the cord is
  **just taut**, then pull about 3 mm more and tie the front knot there.
  That pre-tension is what holds the cap shut.
- Trim to ~8 mm and melt the ends.

Repeat on the other side. Both cords should end up the same length or the
cap will sit crooked.

## Which collar

Five collars are provided. They are drop-in swaps — same cord ears, same
radius, same install direction — so you can fit one of each and decide on
your own hardware.

| | `01` / `01b` screw clamp | `01c` / `01d` / `01e` / `01f` spring rings |
|---|---|---|
| Hardware | M3 screw + hex nut per eye | none |
| Tools | hex key | none |
| Preload | **adjustable, re-tightenable** | fixed by geometry |
| Grip across a diameter range | narrow (0.83 mm stock, 4.14 mm on `01b`) | wide and self-adjusting |
| Rotational security | high, positive | friction only |
| Parts to lose | 2 | 0 |
| Ages by | loosening you can fix | creeping you cannot |

### `01f` is the one to print

`01f_collar_lap` is the recorder mount's actual mechanism, and getting to it
took working out why every earlier ring moved the wrong way.

On `01c`/`01d`/`01e` the tabs sit on the band either side of a **gap**.
Expanding one of those rings opens the gap, so the tabs move *apart* — which
is why all three have to be **spread**. Lap the two ends **past each other**
instead and each tab rides a free **end**. The ends have crossed, so the
angle between the tips *is* the lap; expanding the ring shortens the lap, and
the tips — with the tabs on them — come **together**. Squeeze to expand.
That is a spring hose clip, and it is what the recorder does.

| Collar | Wrap | Fitting | Tab motion | Install strain | Force | Seated |
|---|---|---|---|---|---|---|
| `01c` push-on | 230° | push on radially | spread | 0.65 % | 12.1 N | 0.21 % |
| `01d` lever | 290° | expand, slide on | spread | 0.45 % | 6.5 N | 0.21 % |
| `01e` pinch | 340° | expand, slide on | spread | 0.37 % | 4.9 N | 0.22 % |
| **`01f` lapped** | **414°** | **expand, slide on** | **squeeze** | **0.64 %** | **2.6 N** | **0.22 %** |

*(Ø36.90 barrel, PLA at 2750 MPa, 0.89–0.90 mm interference on all four, so
the seated column is the same by construction and only the cost of getting
there differs.)*

`01f` is much the lightest squeeze of the four and the only one that reads as
a genuinely closed circle. It is not the lowest strain — `01e` is — because
`01f` carries its load through two thin lapped arms rather than one thick
band. 0.64 % still leaves 2.3× margin in PLA and considerably more in
PAHT-CF, and it buys the right *motion*.

#### How the lap is built, and the one thing it forces

Over 54° the band splits in thickness: a 1.20 mm inner arm, a 0.40 mm
sliding gap, a 1.60 mm outer arm. The split is deliberately uneven. The
inner arm gets a full-wall flange back above the gap, so an even split would
leave the outer arm carrying the whole squeeze on a third of the section at
roughly a fifth more strain than it needs to. Moving 0.20 mm of
wall outward and the divide up to 6.5 mm brings the worst case to 0.64 % and
costs nothing.

The step forces one thing: **the inner arm's tab cannot get out radially**,
because the outer arm is in the way and there is no path through it. So the
outer arm stops at 6.5 mm and the inner arm's tab rides over the top of it
on a full-width flange.

Which leaves that tab starting half way up the band with nothing underneath
it outboard of the OD — a fin hanging 6.8 mm in the air, and a slicer is
right to refuse it. Outboard of the band nothing is in the way, so it
carries straight down to the plate, clear of the outer arm by the same
0.40 mm the arms use. Everything on the part now either stands on the plate
or bridges that 0.30 mm gap above the outer arm — a print-in-place
clearance, not an overhang. **No supports anywhere.**

That in turn is why the lap is 54° and not 30°. Tabs at different heights
could lap past each other; two tabs that both reach the bed cannot, so they
have to stay apart. And a tab may not sit *on* its arm's free end — it hangs
half its width past it and welds that arm to the body — so each is inset 7°,
costing another 14°. What is left keeps the heads 9.4 mm apart at rest and
4.3 mm at full squeeze. Insetting does not change the mechanism: the arms
are rigid, so a tab turns with its arm by the same angle wherever it sits.

The heads themselves sit **on** the band — 0.70 mm off the OD — rather than
standing off on a stem. A long stem is a lever arm nothing here needs at a
2.6 N squeeze, and it made the tabs the most snag-prone thing on the part,
standing proud of the cord ears. Pulling them in cost 4° of lap to keep the
two heads from meeting, and the whole tab now sits 1.6 mm *inside* the ears.

> **Check the lap is free before you fit it.** Squeeze the tabs on the bench
> first. If the ring does not visibly grow, the 0.40 mm radial gap or the
> 0.30 mm vertical one has been bridged shut by the slicer and the two arms
> have fused — at which point it is a solid ring and forcing it will break
> it. Turn off any "detect thin walls" or gap-filling option and reslice.

### `01e` — the spread-apart version

`01e_collar_pinch` reads closed at 340°, with two rounded tabs flanking a
narrow gap. You **spread** these, not squeeze them. Kept because it is the
lowest-strain ring in the set and has no sliding clearance to get wrong in
the slicer — if the lap on `01f` fuses, this is the fallback.

> **Neither `01e` nor `01f` can be pushed on. Both go on FIRST, before the
> housing.** Forced on radially, `01e` would need 30.65 mm of spread and
> **2.74 % strain** — 7.5× the axial route, and past PLA's ~1.5 % limit, so
> it would simply break; `01f` laps past itself and cannot open radially at
> all. Neither will pass over the Ø43.7 housing. Fit the collar to the bare
> bezel, then the housing, then the cord. Taking the collar off later means
> pulling the housing first.

### Three mechanisms, not two

`01d` was added after seeing how the BCO recorder mount retains — a ring you
open with your fingers rather than one the hardware forces open. That turns
out not to be a styling choice; it changes what the ring is allowed to be.

A **push-on** ring has to let the barrel through the chord between its tips,
and that chord shrinks fast as the wrap grows — past about 240° the barrel
simply cannot force the gap wide enough. That is what capped `01c` at 230°.

Open it **by hand** and slide it on axially, circlip fashion, and the gap
only has to open by `π × expansion`, which barely changes with wrap. The
constraint disappears:

| Collar | Hardware | Tools | Wrap | Fitting | Gap opens | Install strain | Force | Seated |
|---|---|---|---|---|---|---|---|---|
| `01`/`01b` screw | M3 + nut | hex key | 360° | clamp down | — | — | — | — |
| `01c` push-on C-ring | none | none | 230° | push straight on radially | 5.65 mm | 0.75 % | 13 N | 0.40 % |
| `01d` lever C-ring | none | none | 290° | expand and slide on axially | 7.85 mm | 0.70 % | 9 N | 0.40 % |

So `01d` captures 60° more of the circumference than `01c` *and* takes less
strain and less force to fit. It is strictly the better ring — with one
condition attached.

**It cannot be pushed on radially.** There has to be a clear axial path onto
the barrel. From the front that means over the objective bezel, which is the
smaller diameter, so it should be fine — but it does mean the kill flash
housing comes off before the collar does. If your barrel has no axial
approach, `01c` is the one that works.

To fit `01d`: pinch the two paddles, spread them until the bore clears the
barrel, slide it into place, release. About 9 N at the paddles — firm, not
a struggle.

### Which ring wins depends on the diameter

The lever collar's advantage is **not** unconditional, and it took a
mis-sized test run to notice.

Radial spread scales with the barrel: `D − D_free·sin γ`. Axial spread does
not — it is `π × expansion`, a fixed cost no matter how small the ring gets.
So as the barrel shrinks, the radial route gets cheaper while the axial one
stays put, and somewhere they cross:

| Barrel | `01c` push-on 230° | `01d` lever 290° | Winner |
|---|---|---|---|
| 34 | 0.95 % | 1.01 % | **push-on** |
| 36 | 0.88 % | 0.90 % | **push-on** |
| 38 | 0.82 % | 0.81 % | **lever** |
| 40 | 0.77 % | 0.73 % | **lever** |
| 41 | 0.75 % | 0.70 % | **lever** |
| 43 | 0.70 % | 0.64 % | **lever** |

**Crossover is around Ø38 mm.** Above it the lever ring is strictly better,
as designed. Below it the fixed cost of expanding a small ring by
`π × expansion` outweighs the shrinking chord, and the plain push-on ring is
the better part — on top of which a small seat is likely a *waist* between
two larger diameters, which blocks the axial approach the lever ring needs
in the first place.

Both rings stay in the set for exactly this reason. Gauge the barrel, then
pick.

The barrel came in at **Ø36.90 — below the crossover**, which is why `01c`
and `01d` end up within 0.2 % of each other above and neither is a clear
win. That is the result that made `01e` worth building.

`01e` sidesteps this argument rather than winning it. The crossover exists
because a *push-on* ring gets cheaper as the barrel shrinks while an axial
one does not. At 340° the push-on route is not available at any diameter,
so there is nothing to cross over — the only question left is whether there
is an axial approach, and on this objective there is.

*(Resolved since: `SNAP_INTERF` was a fixed 2.00 mm, which was 4.9 % of a
Ø41 bore but 5.9 % of a Ø34 one. It is now `OBJ_COLLAR_OD × 2.4 %` and
scales with the barrel, as does the pinch ring's.)*

### The snap ring's numbers

Wrap is 230°, so it captures well past the equator. The barrel has to pass
the **chord between the tips**, which is what sets how far the ring flexes:

| Barrel | Interference | Tip spread | Install strain | Seated strain | Margin PLA / PAHT-CF |
|---|---|---|---|---|---|
| 39.2 | 0.20 | 3.85 | 0.51 % | 0.042 % | 2.9x / 4.9x |
| 40.0 | 1.00 | 4.65 | 0.61 % | 0.205 % | 2.4x / 4.1x |
| 41.0 | 2.00 | 5.65 | 0.75 % | 0.400 % | 2.0x / 3.3x |
| 42.0 | 3.00 | 6.65 | 0.88 % | 0.586 % | 1.7x / 2.8x |
| 42.2 | 3.20 | 6.85 | 0.90 % | 0.622 % | 1.7x / 2.8x |

*Install* is transient, while the ring passes over the barrel. *Seated* is
sustained — it is what grips, and it is what creeps.

Two things fall out of that table:

- **Installation is safe everywhere**, with 1.7–2.9× margin in PLA and
  2.8–4.9× in PAHT-CF. The band bends *within* its layers when printed rear
  face down, so this loads X-Y strength and never tests layer adhesion.
- **Grip varies by 15×** across the range, from 0.04 % seated strain on a
  small barrel to 0.62 % on a large one. That is the honest weakness: the
  ring does not know what it is gripping.

### The real decider is creep

A screw clamp holds by a preload you can restore with a hex key. A snap ring
holds by a sustained elastic strain, and every polymer here stress-relaxes —
it will be tightest on the day you fit it and there is nothing you can do
about it afterwards.

That makes the snap ring's viability a **material** question more than a
geometry one. In PLA it is a prototype and nothing more. In PAHT-CF, with a
~170 °C HDT, sustained 0.4 % strain is a much easier ask — which is the same
property that put PAHT-CF on the collar in the first place.

Fit one of each, leave them on the shelf for a month, and see which one you
still trust. That is the test, and it is the reason both exist.

## Why the cap flips the way it does

Both cord holes sit on the same radius (`CORD_RADIUS`, 26.00 mm), so the
line between the two bosses is the hinge axis — and both boss holes lie
**on** that axis. Rotating the cap about it does not change the cord length,
so the bungee only has to stretch the 2.2 mm needed to lift the cap clear of
the register. About 11 % strain on a 20 mm free length: well inside what
1/8 in shock cord does happily, forever.

That is also why nothing needs an anti-rotation key. The cap's orientation
is set by the two cords, not by the register, so the housing is free to sit
at any rotation on the objective.

## Checks after assembly

- Cap closes flat with no rock. If it rocks, the cap is bottoming on the
  register instead of the housing shoulder — increase `CAP_SKIRT_DEPTH`.
- Cap flips up and stays up.
- Collar does not rotate under a firm twist.
- Focus ring still turns freely through its whole range.
- Nothing inside the housing touches the glass.

## Service

Pull the housing off and the kill flash drops out the back for cleaning.
Nothing is bonded, and every fastener is a hardware-store M3.

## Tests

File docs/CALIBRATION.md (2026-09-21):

# Calibration log

This whole design hangs on two hardware diameters, and both were read off a
printed gauge rather than measured directly. A gauge reading is only valid
in the material, printer and settings it was taken in — so it is worth
writing down what those were, because in six months nobody remembers.

Add a row every time you gauge. Fill in the filament SKU and lot: Bambu
reformulates and discontinues filaments, and a calibration pinned to a spool
you cannot re-buy expires silently.

## Readings

### Front bezel — `OBJ_FRONT_OD`

| Date | Pass | Material | Ladder | Result |
|---|---|---|---|---|
| 2026-09-21 | coarse | PLA, 0.60 nozzle | 36.15 → 40.15, 0.50 steps | 36.65 would not go on; 37.15 went on loose → bracketed |
| 2026-09-21 | fine | PLA, 0.60 nozzle | 36.60 → 37.20, 0.10 steps | 36.90 — superseded, read on the wrong hotend |
| 2026-09-21 | **re-gauge** | **PLA, 0.40 nozzle, 0.20 layer** | 36.45 → 37.05, 0.10 steps | **36.85 wins** — mid-ladder, not at an edge |
| 2026-09-21 | **PETG, 0.40/0.12** | PETG | 36.65 → 37.05, 0.10 steps | **36.80 wins** — very tight but goes on; 36.90 slides off |
| | production | PAHT-CF | 36.85 → 37.15, 0.05 steps | *pending — needs a 2–3 week soak before reading* |

**In force:** `OBJ_FRONT_OD = 36.80 − FIT_PRESS = 36.65`, gauged in **PETG on
a 0.40 nozzle at 0.12 layers**. `CAL_MATERIAL` and `PRINT_MATERIAL` are both
PETG, so the bore bias is exactly zero — the only case in the table that is
genuinely *measured* rather than estimated.

PLA at 0.20 read 36.85 on the same criterion. **Material and layer height
moved together**, so that 0.05 belongs to the pair of them and cannot be
split between them from this data. If the layer height changes again, print
a fresh ladder rather than assuming which half it was.

> **A ladder's winner must not land on an end rung.** The first PETG ladder
> went out centred a full `FIT_PRESS` high, because `--nominal` was given a
> winning ring's *label* instead of the objective diameter — the ladder adds
> the fit allowance itself. Its winner landed on the bottom rung, which is a
> bound and not a value. `build.py` now prints the ring labels for every
> gauge it writes, so a mis-centred ladder is visible before it prints. `CAL_NOZZLE` / `CAL_LAYER` now agree with
`NOZZLE` / `LAYER`, so the build summary no longer flags the calibration as
stale.

Confirmed on hardware: the housing built against this number "slides on and
is a very tight fit, and fully bottoms out on the top where it should."

The 0.60 nozzle reading came out 0.05 larger than the 0.40 one, which is the
right sign and about the right size — a fatter nozzle undersizes a hole
more, so the winning *ring* has to be labelled larger to deliver the same
bore. It is worth keeping the superseded row visible for exactly that
reason: it is the evidence that the provenance columns are doing real work.

Worth noting: this is **1.45 mm under** the AN/PVS-14 nominal this project
started from. The nominal was a starting point and it was wrong, which is
the entire reason the gauge exists.

Filament SKU / lot: _________________

### Collar seat — `OBJ_COLLAR_OD`

| Date | Pass | Material | Ladder | Result |
|---|---|---|---|---|
| 2026-09-21 | *triangulated* | — | — | **36.90 assumed**, from the bezel reading — NOT measured |
| | direct | PLA, 0.40 nozzle | `pinch-bore` sweep, 35.60 → 36.80, 0.30 steps | *pending* |

**Still triangulated, not gauged.** The 36.85 ring was read on the front
bezel; the collar sits further back, and nothing has yet been put on that
section of barrel. 36.90 is an inference, and it is the last unverified
dimension in the set.

It is also the one dimension a gauge ring cannot settle on its own. A ring
tells you what diameter slides on; it cannot tell you how much
*interference* a spring ring wants in order to hold the cap's orientation
without being unfittable. So this one is read from the **`pinch-bore`
sweep** instead of a ladder: print all five, fit each over the bare bezel,
and keep the largest bore that still cannot be twisted by hand once seated.
That single plate settles the seat diameter and the grip together.

Criterion, if you do run a plain ladder here: the ring that **just slides
on** with a barely perceptible wobble — a slip fit, not a press. The spring
(or the screw, on 01) takes up the rest.

Filament SKU / lot: _________________

## How to read a ladder

- **Press fit (housing):** the largest ring that still needs firm thumb
  pressure to seat and does **not** fall off when you invert the goggle.
  A ring that needs a mallet is too tight; one that slides on under its own
  weight is too loose.
- **Slip fit (collar):** the ring that just slides on freely with a barely
  perceptible wobble.

Then `OBJ_* = <winning ring label> − <the fit class>`, because the rings are
labelled with their modelled bore and that already includes the allowance.

## Why the material matters so much

A delivered bore is the net of shrinkage, die swell and hole undersize —
all process and material properties, none of them geometry. That is why
`params.py` carries `CAL_MATERIAL` and `PRINT_MATERIAL` rather than a bare
bias number: set them equal and the bias is exactly zero, which is the only
case that is genuinely *measured*.

The clean way to move to production is not to trust the estimate in the
table. Print a fine ladder in the production filament, read it, and set both
material fields to that filament. Everything then cancels identically and
the bias goes back to zero. It costs 15 g and 20 minutes.

**If that filament is a nylon, condition it first.** PAHT-CF takes up
moisture and grows; diffusion through the wall is roughly 12 days to 90 %.
Leave the ladder at ambient for **2–3 weeks** before you judge it. A ring
read at 48 hours is not its final size, and skipping this is the most
likely way to end up with a housing that fits on the bench and is tight a
month later.

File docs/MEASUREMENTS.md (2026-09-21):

# Measurements — do this before you print anything else

Two numbers decide whether this set works or becomes scrap. Everything else
in `params.py` is derived from them.

| Parameter | What it is | Current value |
|---|---|---|
| `OBJ_FRONT_OD` | OD of the **fixed front bezel** the kill flash housing presses onto | **36.75 — bracketed, needs the fine pass** |
| `OBJ_COLLAR_OD` | OD of the **non-rotating barrel section** the collar clamps | **41.00 — STILL UNVERIFIED, and now suspect** |

### Where these stand

The coarse gauge bracketed the front bezel: modelled bore **36.65 would not
go on**, **37.15 went on loose**. So the press fit is between them and near
the bottom of that range — provisional centre 36.90, i.e.
`OBJ_FRONT_OD = 36.90 − FIT_PRESS = 36.75`.

That is **1.3 mm under** the AN/PVS-14 nominal this project started from,
which is a useful thing to know and a warning: `OBJ_COLLAR_OD` is still
sitting on its unverified 41.00 and is very likely wrong by a similar
amount. The coarse collar ladder started at 39.40 and may not have
bracketed it at all. **Do not print a collar until that number is read off
a gauge.**

## Step 1 — measure

With digital calipers, on each objective:

1. **Front bezel OD.** The cylindrical band at the very front of the
   objective, ahead of the focus ring. Take three readings at 60° apart and
   use the **largest**. If the three differ by more than 0.10 mm the bezel is
   out of round; tell me and I will add an ovality allowance.
2. **Front bezel usable length.** How much straight cylinder there is before
   anything steps or knurls. Needs to be ≥ 8.0 mm, or `SHROUD_GRIP_LEN` has
   to come down.
3. **Collar barrel OD.** Pick a band that does **not turn when you focus** —
   this is the one thing most likely to bite. Turn the focus ring and watch:
   whatever moves is off limits. Same three-readings-largest rule.
4. **Collar barrel usable length.** Needs to be ≥ 11.0 mm.

Also worth checking and telling me about:

- Distance from the front bezel face back to where the collar band will sit.
  This sets how much shock cord you need and nothing else.
- Whether the objective already has a sacrificial window or demist shield
  fitted. If it does, the shroud presses onto *that*, not onto the bezel,
  and the diameter is different.
- Interpupillary spacing at the narrowest setting you actually use. The cap
  is Ø52 mm with the cord bosses reaching to Ø60 mm; at a narrow IPD the two
  caps can touch. If that is a problem, `CAP_OD` comes down.

## Step 2 — print the gauges

The gauge is a **null measurement**, and that is the whole trick. Print the
gauge in the same material, on the same plate, with the same first-layer
settings as the real part, and every offset — shrinkage, die swell, hole
undersize, moisture swell — cancels *identically*. You never have to know
what any of them are, and you never have to guess at `BORE_BIAS`.

That means two passes, not one.

### Pass 1 — coarse, in PLA Basic

```
python3 build.py
```

Print `05_gauge_shroud.stl` and `06_gauge_collar.stl`. About 20 minutes
each. PLA is right here: lowest shrink, no drying, no hardened nozzle, and
the most dimensionally honest material on the shelf. This pass brackets the
real diameter and confirms seating depth, cord routing and IPD clearance.

Note the winning ring on each ladder.

### Pass 2 — fine, in the production filament

This is the one that actually sets the number.

```
python3 build.py gauge --nominal <coarse winner> --step 0.05 --count 5
```

Print it in **the exact filament you will produce in**, at your production
settings. About 15 g and 20 minutes.

**If that filament is PAHT-CF (or any nylon), you have to condition it
before you read it.** Nylon absorbs moisture and grows; a ring measured at
48 hours is not its final size. Diffusion through the wall takes roughly
12 days to reach 90 %. Leave it at ambient for **2–3 weeks** before you
judge the fit. The gauge wall is 2.60 mm and the housing wall is 3.40 mm, so
they equilibrate at different rates — give both the full soak.

Skipping this is the single most likely way to end up with a housing that
fits perfectly on the bench and is tight a month later.

## Step 3 — read the gauges

Each ring is labelled with its bore diameter.

- **Shroud gauge:** you want the ring that goes on with *firm thumb
  pressure* and does **not** fall off when you turn the objective upside
  down. That is your press fit. If a ring needs a mallet it is too tight;
  if it slides on under its own weight it is too loose.
- **Collar gauge:** you want the ring that *just slides on* with no force
  and has a barely perceptible wobble. The screw takes up the rest.

Note the number on the winning ring for each.

## Step 4 — set the numbers

Open `params.py` and set:

```python
OBJ_FRONT_OD   = <fine gauge winner>   - FIT_PRESS   # subtract 0.15
OBJ_COLLAR_OD  = <collar gauge winner> - FIT_SLIP    # subtract 0.40
CAL_MATERIAL   = "PLA"        # whatever the gauge was printed in
PRINT_MATERIAL = "PLA"        # whatever you are printing now
```

The rings are labelled with their **modelled bore**, which already includes
the design allowance, so you subtract it back out to recover the hardware
number.

`BORE_BIAS` is no longer a number you set — it is computed as the difference
between `CAL_MATERIAL` and `PRINT_MATERIAL`. Set them equal and it is zero,
which is the case that is actually *measured*. Set them differently and you
get an estimate, flagged as such in the build summary. Then rebuild:

```
python3 build.py && python3 tests.py
```

**Write down the filament SKU and lot number** next to whatever you commit.
Bambu reformulates and discontinues filaments; a calibration pinned to a
spool you cannot re-buy expires silently.

## Step 5 — acceptance test

Before you trust it in the field:

1. Seat the housing. It should take firm thumb pressure.
2. Invert the goggle and shake it. Nothing should move.
3. **Heat soak it** — four hours at 70–80 °C, or an afternoon on a car
   dashboard — and invert again.

If it still holds after the heat soak, you are done. If it loosens, the
material is creeping under the collet's sustained hoop load; that is what
the PAHT-CF recommendation in [PRINTING.md](PRINTING.md) is guarding
against.

## If you are between rings

Run a fine sweep around the winner:

```
python3 build.py gauge --nominal 38.4 --step 0.1 --count 7
```

## If everything is uniformly tight or loose

Do not edit the two hardware numbers — they are a record of your hardware,
not of your printer. Use the trim instead:

```python
BORE_TRIM = +0.10   # every hardware bore 0.10 mm looser
BORE_TRIM = -0.10   # every hardware bore 0.10 mm tighter
```

## Changing material

Change `PRINT_MATERIAL` and rebuild. The offset comes from a table in
`params.py`:

| Printing in | Bias applied, calibrated in PLA |
|---|---|
| PLA, PLA-CF | 0.00 |
| PET-CF | 0.00 |
| PETG | +0.05 |
| ASA | +0.10 |
| PAHT-CF, PPA-CF | +0.10 |

**Only the PLA row is measured; the rest are estimates**, and the build
summary says so whenever the two materials differ. A fine gauge printed in
the production filament beats every one of them and costs 15 g and 20
minutes. Do that before a final set. See [PRINTING.md](PRINTING.md).

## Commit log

2026-09-21 Add parametric NVG objective cap set with fit gauges
    Four-piece 3D-printed objective cap system for PVS-14-pattern objectives
    (NOCTIS glass in Nocturn Raptor housings), retained with 1/8 in shock cord:
    retention collar, kill flash housing, honeycomb kill flash insert, and a
    bungee flip cap. Plus two fit-gauge ladders.
    Built parametrically on manifold3d so the two hardware diameters can be
    dialled in from a gauge print rather than guessed. The nominal values in
    params.py are PVS-14 figures and are flagged as unverified throughout;
    BORE_BIAS gives a single global trim for moving between materials.
    Design points:
    - Both cord holes sit on one radius, so the cord line is the hinge axis and
    th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
    [01_collar.stl, 02_killflash_housing.stl, 03_killflash_insert.stl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]
2026-09-21 Make the shroud grip a four-finger collet
    A solid 3.4 mm wall pressed at +0.15 onto the objective barrel has a narrow
    acceptance window and puts real hoop stress into an expensive optic: 0.1 mm
    over and it splits or scores the barrel, 0.1 mm under and it falls off.
    Four axial slots through the grip section spread the same grip across a much
    wider diameter band at a fraction of the peak stress, and give the print
    somewhere to yield instead of cracking. Slots stop short of the kill flash
    seat so that stays a full ring, and have rounded ends so there is no square
    corner to start a crack.
    Set SHROUD_SLOTS = 0 to go back to a solid ring.
    Adds 11 tests covering slot placement, that the seat abo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
    [01_collar.stl, 02_killflash_housing.stl]
2026-09-21 Add printing guide covering orientation and first-layer compensation
    Documents the one support-free orientation each part is modelled for, and
    the failure mode most likely to waste a print: elephant's foot lands
    directly on the bores that have to fit the objective, so the gauges only
    work if they are printed with the same first-layer compensation, plate and
    settings as the real parts.
    Also covers the thin-wall slicer settings the honeycomb kill flash needs
    (single 0.45 mm extrusion, which slicers drop by default) and how to use
    BORE_BIAS when moving between prototype and production materials.
    Material selection section still to come.
    C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
2026-09-21 Make the collet an actual spring, and add material selection
    A 32-agent analysis of Bambu's filament lineup found two real defects in the
    design, not just a material answer.
    Collet compliance. Radial compliance scales as t^3/L^3, and at the full
    3.4 mm wall over a 6.4 mm slot the fingers were L/t = 1.88 - a stubby plate,
    not a spring. The "wide acceptance window" the previous commit claimed was
    not true as built. There is not enough bezel to lengthen the slots, so the
    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
    [02_killflash_housing.stl, 04_flip_cap.stl, 05_gauge_shroud.stl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]
2026-09-21 Set front bezel from gauge bracket: 36.75, not the 38.00 nominal
    Coarse gauge result: modelled bore 36.65 would not go on, 37.15 went on
    loose. The press fit sits between them and near the bottom, so the
    provisional centre is 36.90 and OBJ_FRONT_OD = 36.90 - FIT_PRESS = 36.75.
    That is 1.3 mm under the AN/PVS-14 figure this project started from, which
    also puts OBJ_COLLAR_OD in doubt - it is still on its unverified 41.00, and
    the coarse collar ladder started at 39.40 so it may not have bracketed at
    all. Marked accordingly; no collar should be printed until it is read.
    CORD_RADIUS is now derived from SHROUD_OD rather than fixed at 26.00, so the
    cord line tracks the hardware instead of leavin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
    [01_collar.stl, 02_killflash_housing.stl, 03_killflash_insert.stl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]
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2026-09-21 Confirm front bezel at 36.75 and start a calibration log
    The fine ladder picked modelled bore 36.90, which is mid-ladder rather than
    at an edge and matches the provisional centre taken from the coarse bracket,
    so OBJ_FRONT_OD stays at 36.75. Marked CONFIRMED in PLA.
    Adds docs/CALIBRATION.md as a durable record. Both hardware diameters in
    this design are gauge readings rather than direct measurements, and a gauge
    reading is only valid in the material, printer and settings it was taken in
    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
    [05_gauge_shroud_nylon.stl]
2026-09-21 Add a wide-gap prototype collar so the set can be built before gauging
    The production collar's 2.60 mm pinch gap is worth only 0.83 mm of diameter
    range. That is correct once OBJ_COLLAR_OD is known and useless before it: a
    collar bored for 41.40 cannot reach a 39.7 barrel, since closing that needs
    pi*1.7 = 5.3 mm of gap. Given the front bezel came in 1.3 mm under its
    nominal, a collar printed against the unverified 41.00 is likely scrap.
    01b_collar_proto opens the gap to 13.00 on a 42.20 bore, which clamps
    anywhere from 42.20 down to 38.06 and covers the whole plausible spread. It
    does not sit as round on a small barrel and needs an M3 x 30 rather than
    x 16, so it is explicitly prototype-on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
    [01b_collar_proto.stl]
2026-09-21 Add a no-tools snap C-ring collar alongside the screw clamp
    Suggested by the recorder mount on the eyepiece, which retains by flexing a
    split ring out of round over a collar rather than clamping. Worth having
    both on the bench to compare on real hardware, so this is a drop-in swap:
    same cord ears, same radius, same install direction.
    Sized from a curved-beam model rather than by eye. Each arm is treated as a
    curved cantilever built in at the crown and loaded at the tip (Castigliano);
    the barrel has to pass the chord between the tips, which is what sets the
    flex. At 230 degrees of wrap the ring captures well past the equator and
    install strain runs 0.51-0.90 % across the whole plausible barr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
    [01c_collar_snap.stl, 05_gauge_shroud.stl, 06_gauge_collar.stl]
2026-09-21 Add a lever-opened circlip collar, which beats the push-on outright
    Prompted by how the BCO recorder mount retains: a ring you open with your
    fingers rather than one the hardware forces open. That is not a styling
    difference, it changes what the ring is allowed to be.
    A push-on ring has to let the barrel through the chord between its tips, and
    that chord shrinks fast as wrap grows - past about 240 degrees the barrel
    cannot force the gap wide enough at all. That is what capped 01c at 230.
    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
    [01d_collar_lever.stl]
2026-09-21 Add a wide low-range collar gauge and document the lever/push-on crossover
    The collar seat may be SMALLER than the front bezel, not larger as the
    nominal 41.00 assumed. If so it sits below every ring on both existing
    collar ladders (40.15-42.65 and 37.00-43.00), so those prints would say
    nothing. 06_gauge_collar_wide spans 30.0-42.0 in 1.2 steps and brackets
    either case.
    Trialling a 34.00 seat through the test suite surfaced a real design limit
    rather than a bug: the lever collar's advantage is diameter-dependent.
    Radial spread scales with the barrel, but axial spread is pi x expansion, a
    fixed cost. As the barrel shrinks the radial route gets cheaper while the
    axial one does not, and they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
    [06_gauge_collar_wide.stl]
2026-09-21 Fix the four defects found in the first printed round
    KILL FLASH - it was built for a pocket that does not exist. The objective
    fills the entire 36.90 bore and bottoms against the back of the internal
    flange, so there was never a rear pocket to seat in. It now presses into the
    33.00 x 3.80 counterbore on the FRONT of that flange and sits 0.20 mm under
    flush, with the cap covering it. 32.70 x 3.60 instead of 36.65 x 5.00.
    KILL FLASH WALLS - 0.45 mm single-extrusion cells were dropped wholesale by
    the slicer; the part came off the plate as a bare rim with stubs. Now
    0.80 mm, exactly two full 0.40 extrusions, which no thin-wall heuristic gets
    a vote on. Cell size retuned to 4.20 to claw back t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
    [01_collar.stl, 01b_collar_proto.stl, 01c_collar_snap.stl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]
2026-09-21 Make the nozzle a design input, and add labelled test sweeps
    The printer is running a 0.60 nozzle at 0.30 layers, not the 0.40/0.20 this
    project was designed around. That single fact explains the kill flash
    failure completely: 0.45 mm cell walls are 75 % of a 0.60 nozzle, below what
    can be extruded at all, so the slicer dropped every one and the part came
    off the plate as a bare rim.
    NOZZLE and LAYER are now design inputs rather than slicer settings, and
    every thin feature derives from them - cell wall, rim, texture groove,
    deboss depth, witness marks. tests.py gains a minimum-feature audit that
    checks all thirteen against the declared nozzle, plus a check that debossed
    detail has at least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
    [01c_collar_snap.stl, 01d_collar_lever.stl, 03_killflash_insert.stl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]
2026-09-21 Allow rebuilding for a different nozzle without editing params
    params.set_nozzle() re-derives every nozzle-dependent feature, and build.py
    takes --nozzle / --layer, so moving between hotends is a flag rather than a
    hand-audit of thin features. --tag now applies to parts as well as gauges,
    so a variant can be built without clobbering the main output.
    Documents when the switch is actually worth making. A nozzle change
    invalidates the fit calibration - a different nozzle delivers a different
    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
    [04_flip_cap_fine.stl]
2026-09-21 Export the cap and housing already oriented for printing
    Both were modelled rear-face-down but documented as front-face-down, so
    every copy had to be rotated 180 degrees by hand before slicing. That is not
    a documentation problem, it is a file problem: the housing was printed
    unflipped and strung the whole way up its bore, and the user was left
    apologising for a mistake the file invited.
    build.orient() now applies the print orientation before export, so both drop
    straight onto the plate. Parts already modelled plate-side-down are passed
    through untouched, and a test asserts both cases by probing a feature whose
    side is known rather than by guessing from the bounding box.
    Worth recording wh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
    [02_killflash_housing.stl, 04_flip_cap.stl, 04_flip_cap_fine.stl]
2026-09-21 Move to a 0.40 nozzle at 0.20 layers, and flag the stale calibration
    Switching hotends invalidates every fit number in the project. A delivered
    bore is as much a property of the nozzle as of the material - a 0.60 nozzle
    undersizes a hole by roughly 0.20-0.35 mm and a 0.40 by roughly 0.10-0.20 -
    so the shift is larger than the entire 0.15 mm design clearance on the
    housing. The press fit that currently works will have become a slip fit.
    Calibration provenance now records the hotend, not just the material.
    CAL_NOZZLE and CAL_LAYER sit alongside CAL_MATERIAL, and the build summary
    prints "*** CALIBRATION STALE - RE-GAUGE ***" until they agree with what is
    actually being printed. That is the wh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
    [03_killflash_insert.stl, 04_flip_cap.stl, 05_gauge_shroud.stl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]
2026-09-21 Add the lapped collar, the one that squeezes to expand
    01e had the tabs on the band either side of a gap. Expanding that ring
    opens the gap, so the tabs move APART and it has to be spread - which is
    the opposite of the motion the recorder mount actually uses, and the
    opposite of what was asked for twice.
    Lap the two ends PAST each other and each tab rides a free END. The ends
    have crossed, so the angle between the tips IS the lap; expanding the ring
    shortens the lap and brings the tips, and the tabs on them, together.
    Squeeze to expand. That is a spring hose clip.
    01f builds it as a 390 degree band split in thickness over 30 degrees:
    1.20 inner arm, 0.40 sliding gap, 1.60 outer arm. The sp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
    [01_collar.stl, 01b_collar_proto.stl, 01c_collar_snap.stl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]
2026-09-21 Fix three ways the lapped collar was welded solid, and the slicer warning
    Bambu Studio flagged lap_35.60 as a floating cantilever. It was right, and
    chasing it turned up three separate defects - every one of which still gave
    one watertight shell with the correct bore and a render that looked
    perfect, so nothing in the test suite had a word to say about them.
    1. FLOATING CANTILEVER. The upper tab starts above the outer arm so it can
    get out past it, and outboard of the band OD there is no material at any
    height - so it was a 10 x 4.2 mm fin hanging 6.8 mm in the air. Outboard
    of the band nothing is in the way, so it now carries down to the plate,
    clear of the outer arm by the sam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
    [01f_collar_lap.stl, lap_35.60.stl, lap_35.90.stl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]
2026-09-21 Pull the tab heads in onto the band
    The heads stood off on a 7 mm stem. That is a lever arm nothing here needs -
    the squeeze is under 3 N either way - and it made the tabs the furthest
    thing out on the part, standing proud of the cord ears, which are the one
    feature on this assembly that is supposed to catch something.
    PINCH_TAB_PROJ 7.00 -> 4.00 puts the head's inner edge 0.70 mm off the band
    OD, so it reads as a circle stemming straight off the ring. Whole tab pulls
    3 mm in, to 1.6 mm INSIDE the cord ears. Applies to 01e as well as 01f.
    Pulling the heads in shortens the radius they swing on, so the same angular
    travel leaves them closer together: 01f's lap goes 50 -> 54 deg to hold
    4.3 m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
    [01e_collar_pinch.stl, 01f_collar_lap.stl, lap_35.60.stl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]
2026-09-21 Add 01g, a cinch collar that is held by a zip tie rather than by the plastic
    Every ring so far asks PLA to be a spring, and the printed 01f confirmed
    what that is worth on hardware. Reduced to the same terms - an equivalent
    band tension, since a split ring carries no hoop load and grips only by
    bending back toward its free shape:
    01f, PLA spring : 6.1 N equivalent -> 0.21 Nm of twist resistance
    01g, 3.6 mm tie : 40 N hand-tight -> 1.39 Nm, and re-tensionable
    0.21 Nm is a collar you can turn with your fingers, which is exactly the
    reported behaviour, and PLA sheds a third of even that in the first week.
    The tie is 6.6x better on the day and does not decay at all. It is also
    gentle: 40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
    [01g_collar_cinch.stl, cinch_37.20.stl, cinch_39.20.stl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]
2026-09-21 Pin the collar seat to the locking collar, and make 01g fit it
    The seat is the FIXED locking collar immediately behind the focus ring, not
    the front bezel the housing grips. Two reasons, and the second is stronger
    than the first:
    1. The bezel turns to focus and has play in it. Hanging the collar, the
    cord tension and the cap's weight off a rotating part is asking for a
    stiff focus.
    2. The cap's register on the housing is CIRCULAR, so nothing about it sets
    rotation - the cap's orientation is held entirely by the two cords, and
    the cords anchor to this collar. On the fixed band, focusing just spins
    the housing underneath the cap and the thumb tab stays where it w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
    [02b_killflash_housing_solid.stl, cinchS_37.20.stl, cinchS_39.20.stl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]
2026-09-21 Replace the cap's chevron with the traced blackletter P, and fix the face
    The mark is now traced from supplied artwork rather than generated. The
    tracer (tools/trace_mark.py) runs once and writes lib/mark_data.py, so the
    build never depends on an image file or on PIL.
    The opening pass in the tracer is not optional. Blackletter is full of
    hairline flourishes, and on this glyph 18 % of the area sits in strokes
    under one extrusion width at any size that fits the cap. A debossed groove
    narrower than the nozzle is not a fine groove, it is no groove - the slicer
    omits it silently, exactly as it omitted the first kill flash's cell walls.
    So the mask is morphologically opened at 0.55 mm first, whic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
    [04_flip_cap.stl]
2026-09-21 Fix cord holes filled in by the band, and take the cap's hex across the face
    THE BUG. The cinch collar's cord hole was cut inside _ear(), before the ear
    was unioned with the band. The hole sits at a FIXED radius while the band's
    rim grows with the bore, so past about a 39 mm bore the band grew out under
    the hole and filled it straight back in:
    bore 37.20 hole 3.92 radial x 3.92 tangential round
    bore 39.20 3.70 x 3.92
    bore 41.20 2.70 x 3.92 a D, not a hole
    Reported from the printed parts - "the holes on the larger ring appear half
    flattened". Every one of those still passed topology, volume, and a probe
    down the hole's own centre line, becau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
    [01g_collar_cinch.stl, 04_flip_cap.stl, cinchS_37.20.stl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]
2026-09-21 Move to 0.12 layers, and stop deriving detail depth from layer height
    DETAIL_DEPTH was LAYER * 3, which has the dependency backwards. Finer layers
    would give SHALLOWER detail, so dropping from 0.20 to 0.12 would quietly
    have taken the hex dimples and the P from 0.60 deep to 0.36 and washed the
    whole cap out - a cosmetic regression caused by choosing a better print
    setting, which is the wrong way for a parameter to behave.
    Depth is a design intent: how pronounced should the feature look. The layer
    height is a CONSTRAINT on it, not its source. So DETAIL_DEPTH is now a fixed
    0.60 and tests.py enforces at least three layers behind it. At 0.12 that is
    five layers; at 0.30 it would fail, correctl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
    [cinchS_37.20.stl, cinchS_39.20.stl, cinchS_41.20.stl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]
2026-09-21 Add a fine PETG gauge ladder for the housing bore
    Five rings, 36.65 to 37.05 in 0.10 steps, centred on the 36.85 that PLA read.
    18 cm3 against the full ladder's 41, so it is a 20 minute print rather than
    an hour.
    Only one fit in the set moves with material. The kill flash press cancels,
    because both parts are the same material and shift together; the cap's
    register is a clearance, not a fit; and the cinch collar closes 1.91 mm of
    diameter, so it cannot tell PLA from PETG. That leaves the housing's press
    onto the aluminium bezel, where PETG's estimated +0.05 takes a third of the
    0.15 allowance.
    A third of the allowance is inside what the collet is there to absorb, but
    it is an estimate from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
    [05_gauge_shroud_petg.stl]
2026-09-21 Print gauge ring labels, and reissue the PETG ladder centred correctly
    --nominal takes the OBJECTIVE diameter and the ladder adds `fit` to it. I
    passed the winning RING LABEL instead, which is already a diameter plus a
    fit, so the whole ladder went out centred a full allowance high: 36.80 to
    37.20 where it should have been 36.65 to 37.05. I then described it in
    chat as 36.65 to 37.05, which it was not.
    The consequence is not cosmetic. The PETG reading came back on the bottom
    rung, and a winner on the end of a ladder is a BOUND, not a value - it says
    the answer is at or below 36.80 and nothing more. Centred properly, 36.80
    would have been the second rung with two below it.
    So build.py now p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
    [05_gauge_shroud_petg2.stl]
2026-09-21 Gauge the housing bore in PETG: 36.80, and move the calibration onto it
    The corrected ladder brackets rather than bounds. 36.80 is very tight but
    goes on; 36.90 is loose enough to slide off. That is the criterion exactly,
    with a rung either side of it.
    So OBJ_FRONT_OD becomes 36.65 (= 36.80 - FIT_PRESS) and CAL_MATERIAL,
    CAL_NOZZLE and CAL_LAYER move to PETG 0.40/0.12 alongside PRINT_MATERIAL.
    Bias goes to exactly zero, which is the only row in the table that is
    genuinely measured rather than estimated - everything downstream is printed
    on the same setup, so the process offset cancels instead of being guessed.
    OBJ_FRONT_OD is not a caliper reading of the bezel and is not meant to be.
    It is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
    [01_collar.stl, 01b_collar_proto.stl, 01c_collar_snap.stl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]
2026-09-22 Add custom-text cap faces, and test every mark instead of just the default
    tools/trace_mark.py grows a --text mode: render with PIL, then run the same
    run-length trace and morphological opening the artwork already goes through.
    Reusing the raster path rather than pulling glyph outlines from the font is
    deliberate - the opening pass is the part that matters and it wants a raster
    anyway, and it means text and artwork are held to the same minimum stroke.
    python3 tools/trace_mark.py --text FUCK --height 9.5 --out mark_fuck
    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
    [04b_flip_cap_FUCK.stl, 04c_flip_cap_YOU.stl]
2026-09-22 Add multicolour inlays for the cap face, lettering and hex field
    Every recess on the decorated face now has a matching solid that fills it
    exactly flush, so the face can be printed in two or three filaments.
    04_inlay_mark / 04_inlay_hex
    04b_inlay_FUCK / 04b_inlay_hex_FUCK
    04c_inlay_YOU / 04c_inlay_hex_YOU
    Flush rather than part way, for two reasons. A partial fill would leave the
    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
    [04_inlay_hex.stl, 04_inlay_mark.stl, 04b_inlay_FUCK.stl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]
2026-09-22 Add combined build plates: a whole set in one STL
    10_plate_set one pod, four parts 180 x 97 mm
    11_plate_pair a binocular set, eight 204 x 151 mm
    12_plate_caps_FUCK_YOU both custom caps 128 x 56 mm
    Shelf-packed with 8 mm between footprints, which is a brim's width - the
    cap is a 52 mm flat plate and lifts at a corner without one. Parts stay
    separate shells; manifold's union of disjoint solids keeps them disjoint,
    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
    [10_plate_set.stl, 11_plate_pair.stl, 12_plate_caps_FUCK_YOU.stl]
2026-09-22 Add 3MF export: the format that actually carries colour
    An STL is a bag of triangles with no notion of a part, a colour or a
    filament, so "combine the cap and its lettering into one STL" can only ever
    produce one grey object - which is what it produced. The inlays were right;
    the container was not.
    tools/make_3mf.py writes a Bambu Studio project instead. Each cap is a 3MF
    <components> assembly - one child object per part - with
    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
    [20_cap_FUCK_2color.3mf, 21_cap_YOU_2color.3mf, 22_caps_FUCK_YOU_2color.3mf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]
